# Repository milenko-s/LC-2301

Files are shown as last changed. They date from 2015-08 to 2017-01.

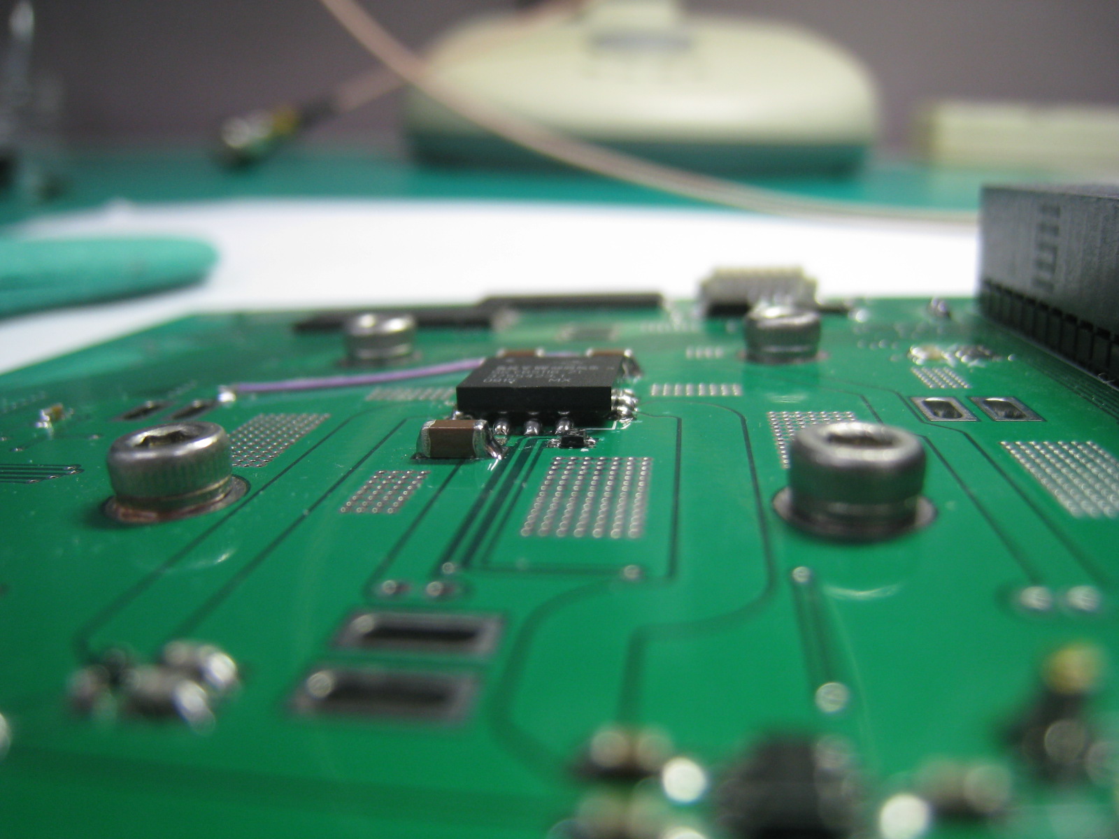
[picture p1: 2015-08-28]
documentation/pictures/IMG_1647.JPG

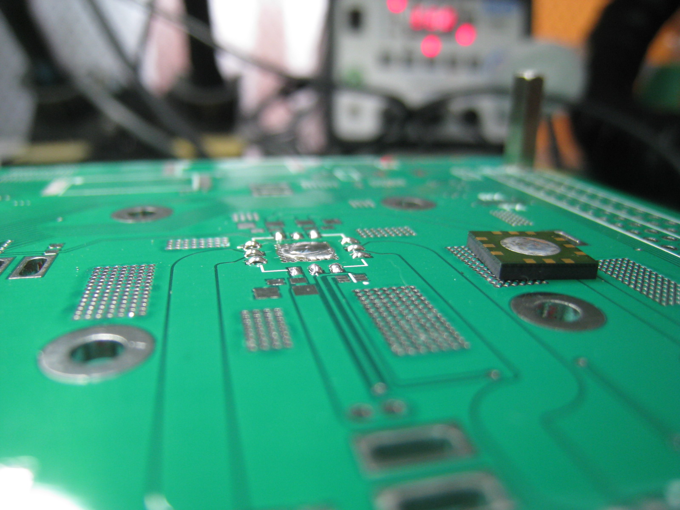
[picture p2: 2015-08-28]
documentation/pictures/IMG_1648.JPG

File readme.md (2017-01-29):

# LibreCube LC-2301 Communication System

## About

Half-duplex communication system for UHF band operation with radio output power of up to 31 dBm (>1 W). The output power, as well as the frequency and frequency separation are user-programmable, allowing large flexibility in operation. The device includes a beacon function that sends out a user-defined message in Morse code at adjustable keying speed, useful for satellite tracking and identification. The heart of the device is the establishment of a space link via ECSS/CCSDS compliant telecommand and telemetry frames (more correctly, CLTUs and CADUs, respectively). Beacon and telemetry frames are created and transmitted whenever such data is written to the device from an external device. Incoming telecommand frames are buffered in the device's memory, for successive read out from an external device. The physical layer of the space link uses FSK modulation at a data rate of 1200 bps (user-programmable). Further, a mechanism to support antenna deployment is included.

## Authors

- Artur Scholz [artur.scholz@librecube.net]
- Jesus Sanchez []
- Milenko Starcik []

## Acknowledgements

- Development supported from National Cheng Kung University (www.ncku.edu.tw) under supervision of Prof. Jiun-Jih Miau and Prof. Jyh-Ching Juang and with the help from students of PACELAB and MECLAB.

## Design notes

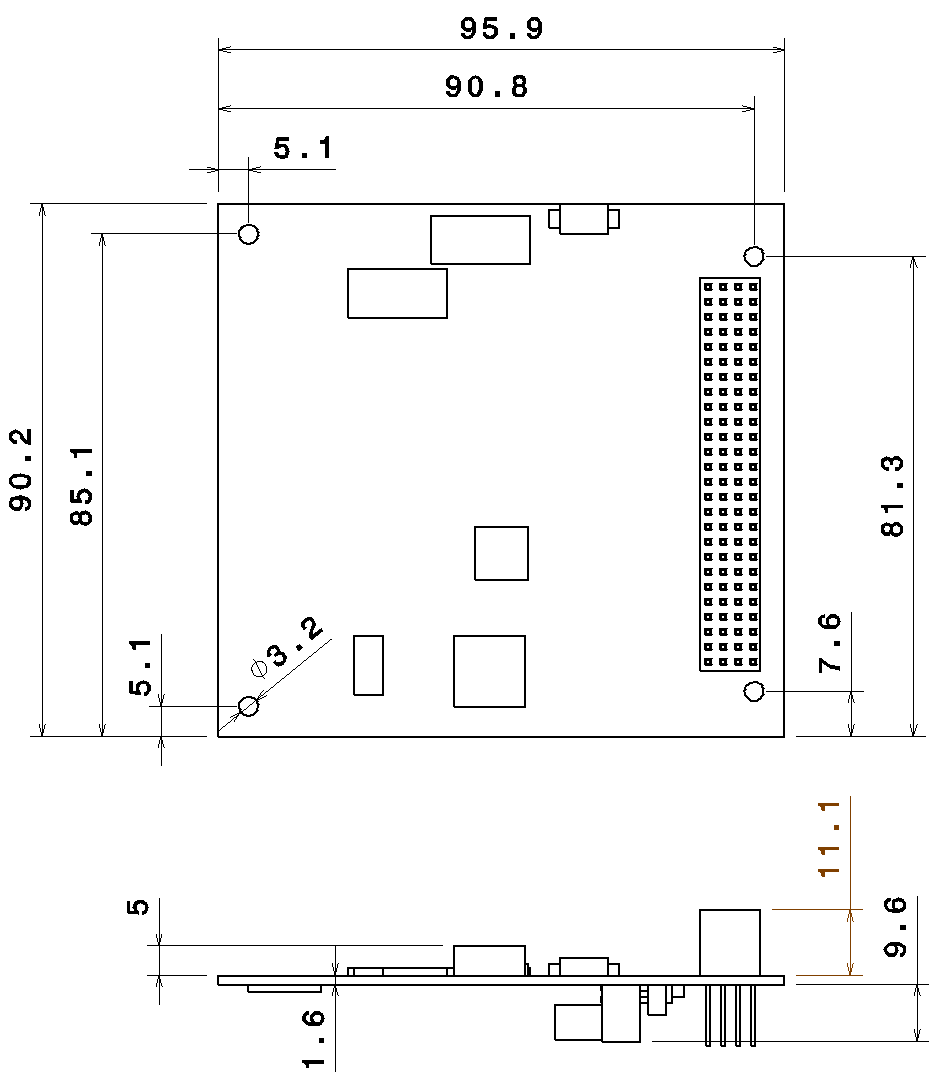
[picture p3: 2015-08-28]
documentation/figures/mechanical layout.tif

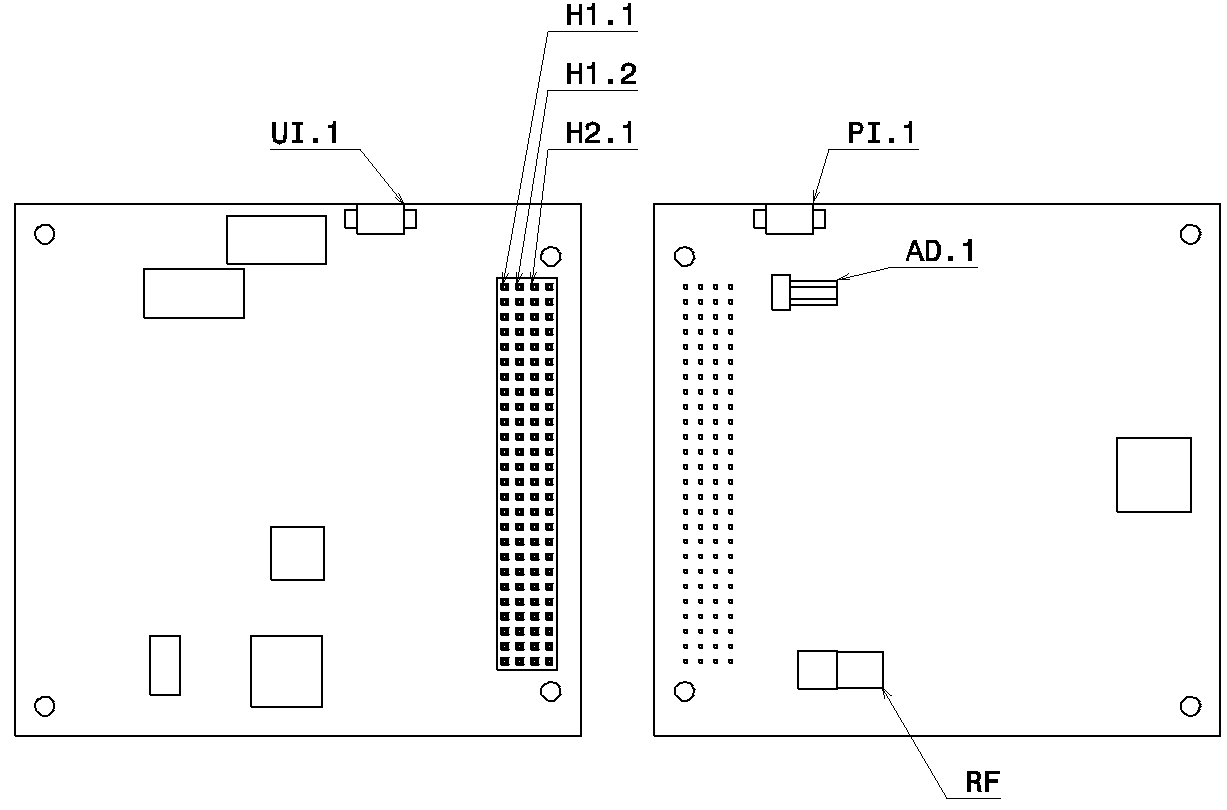
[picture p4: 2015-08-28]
documentation/figures/connector layout.tif

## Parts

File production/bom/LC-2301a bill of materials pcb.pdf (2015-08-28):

Sheet1

Page 1

LC-2301a Bill of Materials, PCB

Pos | Type | Description | Reference Designators | Qty | Vendor | Part Number | Unit Cost | Total Cost
1 | C | 0.1 uF | C1a, C1c, C1d, C4a, C5a | 5 | Digikey | 399-1097-1-ND | 0.10 € | 0.50 €
2 | C | 15 pF | C1e | 1 | Digikey | 445-1271-1-ND | 0.09 € | 0.09 €
3 | C | 0.01 uF | C1g, C3g, C5g, C7g | 4 | Digikey | 445-1311-1-ND | 0.09 € | 0.36 €
4 | C | 18 pF | C2a, C11e, C12e | 3 | Digikey | 445-1272-1-ND | 0.09 € | 0.27 €
5 | C | 0.47 uF | C2c | 1 | Digikey | 490-3295-1-ND | 0.18 € | 0.18 €
6 | C | 12 pF | C2e | 1 | Digikey | 445-1270-1-ND | 0.09 € | 0.09 €
7 | C | 10 uF | C2g, C4g, C6g, C8g | 4 | Digikey | 587-2562-1-ND | 0.56 € | 2.24 €
8 | C | 20 pF | C3a | 1 | Digikey | 478-7912-1-ND | 0.20 € | 0.20 €
9 | C | 220 pF | C3e | 1 | Digikey | 445-1285-1-ND | 0.09 € | 0.09 €
10 | C | 1 uF | C4e | 1 | Digikey | 490-5241-1-ND | 0.31 € | 0.31 €
11 | C | 8.2 pF | C5e | 1 | Digikey | 478-4997-1-ND | 0.21 € | 0.21 €
12 | C | 5.6 pF | C6e | 1 | Digikey | 399-9110-1-ND | 0.22 € | 0.22 €
13 | C | 3.3 uF | C7e | 1 | Digikey | 445-5168-1-ND | 0.25 € | 0.25 €
14 | C | 1 nF | C8e, C10e | 2 | Digikey | 490-1451-1-ND | 0.13 € | 0.26 €
15 | C | 33 nF | C9e | 1 | Digikey | 445-5093-1-ND | 0.09 € | 0.09 €
16 | C | 68 pF | C13e | 1 | Digikey | 445-1279-1-ND | 0.09 € | 0.09 €
17 | D | LED | D1a, D2a | 2 | Digikey | 160-1447-1-ND | 0.26 € | 0.52 €
18 | P | CubeSat ConnectoH1b | | 1 | Samtec | ESQ-126-39-G-D | 9.29 € | 9.29 €
19 | P | CubeSat ConnectoH2b | | 2 | Samtec | ESQ-126-39-G-S | 5.45 € | 10.90 €
20 | L | 12 nH | L1a | 1 | Digikey | PCD2003CT-ND | 0.12 € | 0.12 €
21 | L | BLM18HG102SN1L1e, L4e | | 2 | Digikey | 490-1034-1-ND | 0.17 € | 0.34 €
22 | L | 68 nH | L2e | 1 | Digikey | PCD2012CT-ND | 0.12 € | 0.12 €
23 | L | 6.2 nH | L3e | 1 | Digikey | 490-1163-1-ND | 0.29 € | 0.29 €
24 | L | 33 nH | L5e | 1 | Digikey | PCD2008CT-ND | 0.12 € | 0.12 €
25 | P | SMA | P1a | 1 | Digikey | ARFX1232-ND | 5.59 € | 5.59 €
26 | P | 2POS | P2a | 1 | Digikey | 732-2699-ND | 0.51 € | 0.51 €
27 | P | MICRO-06-R-SMTP3a | | 1 | Digikey | WM7624CT-ND | 1.44 € | 1.44 €
28 | R | 0.1 r | R1a | 1 | Digikey | CRA2512-FZ-R100ELFCT-ND | 0.63 € | 0.63 €
29 | R | 4.75 k | R1c | 1 | Digikey | P4.75KHCT-ND | 0.09 € | 0.09 €
30 | R | 10 k | R1e, R1f, R1g, R2a, R3g | 5 | Digikey | 311-10.0KHRCT-ND | 0.09 € | 0.45 €
31 | R | 100 k | R2c | 1 | Digikey | 311-100KGRCT-ND | 0.09 € | 0.09 €

Sheet1

Page 2

32 | R | 27 k | R2e | 1 | Digikey | RMCF0603JT27K0CT-ND | 0.09 € | 0.09 €
33 | R | 1.1 k | R2g | 1 | Digikey | P1.1KGCT-ND | 0.09 € | 0.09 €
34 | R | 1.5k | R3a, R4a | 2 | Digikey | P1.5KGCT-ND | 0.09 € | 0.18 €
35 | R | 82 k +/- 1% | R3e | 1 | Digikey | P82.0KHCT-ND | 0.09 € | 0.09 €
36 | R | 0 r | R5a, R6a | 2 | Digikey | P0.0GCT-ND | 0.09 € | 0.18 €
37 | IC | AS193-73 | U1a | 1 | Digikey | 863-1006-1-ND | 0.75 € | 0.75 €
38 | IC | C8051F120 | U1c | 1 | Digikey | 336-1223-ND | 15.65 € | 15.65 €
39 | IC | IS62WV5128BLL-5U1d | | 1 | Digikey | IS62WV5128BLL-55TLI-TR | 3.83 € | 3.83 €
40 | IC | CC1000 | U1e | 1 | Digikey | 296-19576-1-ND | 6.52 € | 6.52 €
41 | IC | TPS2024D | U1f, U2a | 2 | Digikey | 296-2564-1-ND | 2.23 € | 4.46 €
42 | IC | MAX893L | U1g | 1 | Digikey | MAX893LESA+-ND | 1.86 € | 1.86 €
43 | IC | REF3130 | U2c | 1 | Digikey | 296-17098-1-ND | 2.60 € | 2.60 €
44 | IC | RAMP-33LN+ | U2f | 1 | Digikey | *MINI-CIRCUITS: RAMP-33LN+ 18.77 € | | 18.77 €
45 | IC | SKY65116 | U2g | 1 | Digikey | 863-1072-1-ND | 5.34 € | 5.34 €
46 | IC | TMP20 | U3g | 1 | Digikey | 296-25570-1-ND | 0.98 € | 0.98 €
47 | X | 14.7456MHz_16pFX1e | | 1 | Digikey | 535-9633-1-ND | 0.81 € | 0.81 €
Total: | 98.15 €

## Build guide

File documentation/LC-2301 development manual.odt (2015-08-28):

Developer Manual

Communication System

Document change log

Rev. | Date | Author | Pages | Description
0 | 2014-06-27 | Artur Scholz | All | Created
1 | 2014-10-13 | Artur Scholz | 7 | Added information

# Introduction

This document provides the necessary information for production, assembly and firmware flashing of the product as shown in Illustration 1.

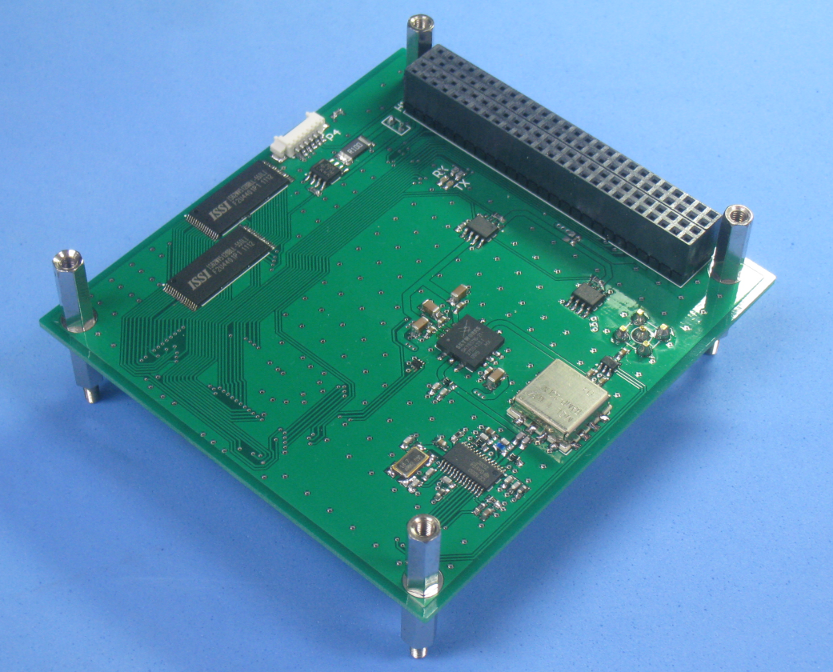
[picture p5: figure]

Illustration 1: Fully assembled product

# Applicable and reference documents

Reference | Title | Issue

# Definitions and abbreviations

Abbreviation | Definition

# Hardware

The product consists solely of a printed circuit board (PCB) assembly. The bill of materials (BOM) provides the list of items needed for the PCB assembly.

## PCB

With the provided Gerber files the double-sided PCB can be produced.

Good PCB layout is crucial to successful working and good performance. The reference layouts for the transceiver and power amplifier were closely followed. A high number of vias was used to interconnect all ground planes. The RF signal tracks to and from the power amplifier were given a width of 3.2 mm (rule of thumb: two times the height of the PCB) to yield 50 Ohm impedance.

The components are hand-soldered onto the PCB. The first part to mount is the high power amplifier (HPA). Attach small dots of solder tin on each pin of the IC and a larger and distributed amount on the center. Do the same for the pads on the PCB (Illustration 2). Key point is to have a solder film on each of the contacts. (It is absolutely important that the center pin has electrical contact!) Place the IC on the PCB and hold it in position with a Kapton tape (Illustration 3). Heat up the solder iron to around 450 °C, and hold it against the center pin vias from the other side of the PCB. Wait several seconds until it becomes apparent that the solder under the IC is liquid, and then remove the iron. In most cases it will be necessary to check the edge pins and solder them again after this procedure.

Illustration 2: Solder tin on pads

Illustration 3: Fixation of HPA chip

Using conductive glue instead of soldering for mounting the HPA is not recommended as it often results in poor conduction. After mounting, check the power amplifier module’s bias current (around 0.350 A without input signal) and output signal levels.

Next to mount is the TR switch, followed by transceiver and filter. Conduct test of the transceiver by checking its frequency range (smaller value for VCO inductor shifts to higher frequency) and check current consumption (in particular check that bias resistor is correct).

# Firmware

The firmware is the code that shall be programmed into the microcontroller on the PCB. The firmware has already been compiled and linked and is available as .OMF file for flashing (i.e. programming) of the microcontroller as explained in Section Flashing.

## Code editing and compiling/linking

A great and open source compiler for 8051 microcontrollers is SDCC (http://sdcc.sourceforge.net). This is the compiler used for generating the code contained in the repository. Alternatively one can use for example the free KEIL compiler.

As development environment, the author recommends the Eclipse platform with the SDCC plugin. This works great for Linux.

Alternatively, a Windows based IDE is the Silicon Laboratories IDE, which also provides for a debugger.

## Flashing

The flashing of the firmware code (as .OMF file) into the microcontroller is done using a USB JTAG Debug Adapter from Silicon Laboratories and the Silabs IDE. This only works with Windows unfortunately.

For the connection of the debug adapter to the device, a small interface board must be used in between, such as the LC-6101a. Alternatively, one can route the wires via a breadboard setup.

# Calibration

## Frequency and frequency separation calibration

The TX frequency settings should be programmed after the centre frequency and frequency deviation is defined. The 3-byte value to be written in the transceiver register is obtained for a desired frequency according to:

For the TX frequency, replace X with the desired centre frequency minus frequency deviation. For the RX frequency, replace X with the desired centre frequency minus 150 kHz. Also note that although the formula is quite accurate it is necessary to tune the values by hand to obtain a perfect result for each individual device.

For the frequency separation (which is twice the frequency deviation from the centre frequency), the formula for determining the 2-byte register value is:

This yields a value of 13.333 for a 1 kHz separation.

## RSSI measurement

For calibration of the RSSI measurement, a signal generator shall be connected to the RF terminal. The input signal is set to the frequency and frequency separation as programmed for the transceiver, and its output power is varied, while noting down the RSSI measurements. Obtain gain and offset from a linear least square fitting line.

## Temperature measurements

For calibration of the temperature measurements, the device shall be put in a thermally controlled environment, with temperature sensors placed on the temperature measurement locations. The measured temperatures together with the reference measurements shall be noted down for various temperatures. Obtain gain and offset from a linear least square fitting line.

Communication System Ref : LC-2301-MAN-01 Issue : 1 Rev. : 1 Date : 2014-10-13 LC-2301 Page : 6

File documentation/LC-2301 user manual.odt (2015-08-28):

User Manual

Communication System

Document change log

Rev. | Date | Author | Pages | Description
0 | 2014-06-27 | Artur Scholz | All | Created
1 | 2014-12-23 | Artur Scholz | All | Major revision

# Introduction

The LC-2301a Communication System is a half-duplex communication system for UHF band operation with radio output power of up to 31 dBm (>1 W). The output power, the frequency and the frequency separation are user-programmable, allowing large flexibility in operation. The main function of the device is the receiving of telecommands and sending of telemetry over the space link and exposing this to the UART interface. The space link implements ECSS/CCSDS telecommand and telemetry frames (namely, CLTUs and CADUs). The physical layer of the space link uses binary FSK modulation at a default data rate of 1200 bps (user-programmable). Further, a mechanism to support antenna deployment is included.

Features:

- CubeSat and CubeSat Kit compatible with PC/104 form factor
- Industrial temperature range
- RF output power up to 31 dBm
- ECSS/CCSDS frame protocol for telecommands and telemetry
- Transceiver completely programmable
- Binary FSK at 1200 bps
- Operates in the UHF band (amateur radio band)
- Includes provisions for antenna deployment

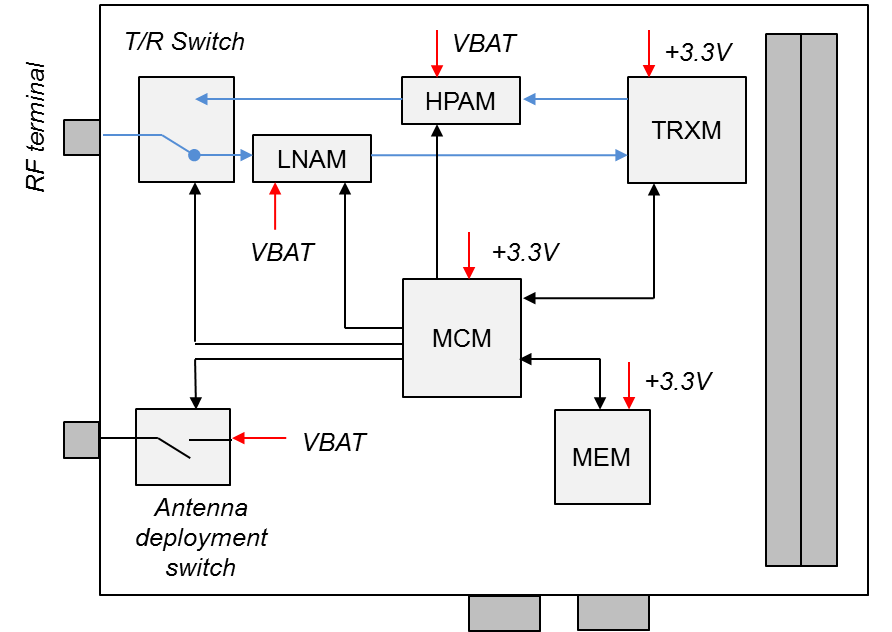
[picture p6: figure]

Illustration 1: System block diagram

# Applicable and reference documents

Reference | Title | Issue
AD01 | LibreCube Board Specification | 1

# Definitions and abbreviations

Abbreviation | Definition
ASM | Attached sync marker
CCSDS | Consultative Committee for Space Data Systems
CLTU | Communications link transmission unit
ECSS | European Cooperation on Space Standardization
HPAM | High power amplifier module
LNAM | Low noise amplifier module
MCM | Microcontroller module
MEM | Memory module
MSB | Most significant bit
RF | Radio frequency
RSSI | Received signal strength indication
TC | Telecommand
TM | Telemetry
TNC | Terminal node controller
TRXM | Transceiver module
WPM | Words per minute

# Specification

## Absolute maximum ratings

Parameter | Min | Max | Unit
Operational temperature range | -40 | 85 | °C
Supply voltage on +3.3V | | 3.6 | V
Supply voltage on VBAT | | 4.5 | V

| Exceeding the limits specified in the table above may result in permanent damage to the device and harm to products and personal.

## Physical characteristics

Parameter | Min | Nom | Max | Unit
Total mass | | 62.7 | | g
Height above PCB | | | 5 | mm
Height below PCB | | | 9.6 | mm
PCB width | | 95.9 | | mm
PCB length | | 90.2 | | mm
PCB thickness | | 1.6 | | mm

## Electrical characteristics

Parameter | Min | Nom | Max | Unit
Supply voltage on +3.3V | 3.0 | 3.3 | 3.6 | V
Supply voltage on VBAT* | 3.2 | 3.6 | 4.0 | V
Power consumption on +3.3V (idle) | | | 50 | mW
Power consumption on +3.3V (active) | 56 | | 66 | mW
Power consumption on VBAT (active) | 1.2 | | 4.2 | W
I2C node address (7 bit, hex) | | 0x13 | | -
I2C operating frequency | | 50 | 100 | kHz
Microcontroller operating frequency | | 6.125 | | MHz
Measurement resolution | | 12 | | bit
UART baud rate | | 9600 | | bps

*VBAT powers the LNAM and the HPAM

## RF and interface characteristics

Parameter | Min | Nom | Max | Unit
Antenna impedance (SMA connector) | | 50 | | Ohm
Centre frequency | 300 | 437 | 500 | MHz
Frequency programming steps | | 250 | | Hz
Frequency separation | 0 | 9.6 | 65 | kHz
Frequency sep. programming steps | | 250 | | Hz
RF baudrate | | 1200 | | bps
Transmit power | -17 | | 31 | dBm
Receiver sensitivity (BER = 10⁻³) | -95 | -105 | | dBm
Size of telecommand data buffer | | 65536 | | Byte
Size of telemetry data buffer | | 65536 | | Byte

# Interfaces

## Mechanical interfaces

The mechanical layout of the device is shown in Illustration 2. Four ø3.2 mm holes are located on the corners for mounting with M3 screws. The CubeSat connector is available in stack-through (as shown) and non-stack-through option.


Illustration 2: Mechanical layout

## Electrical interfaces

All available connectors on the top and bottom of the board are shown in Illustration 3. Note that the arrow points to the location of pin 1 for each connector. The signals of each connector are described in Table 1 to Table 4.


Illustration 3: Connector layout

Table 1: Antenna deployment connector

Pin | Description
AD.1 | Connects to battery supply during deployment. Otherwise open.
AD.2 | Ground

Table 2: RF interface connector

Pin | Description
- | RF signal
- | Ground (shielding)

Table 3: Programming interface connector

Pin | Signal | Description
PI.1 | +3.3V | +3.3V power supply
PI.2 | TMS | JTAG TMS signal
PI.3 | TCK | JTAG TCK signal
PI.4 | TDI | JTAG TDI signal
PI.5 | TDO | JTAG TDO signal
PI.6 | GND | Ground.

| The programming interface is used for updating the firmware.

Table 4: CubeSat connector

Pin | Signal | Description
H1.29 | -RESET | System reset line. Active low. Causes MCU to reboot.
H1.39 | TX0 | TX of UART0 for data to be transmitted via communication system.
H1.40 | RX0 | RX of UART0 for data received via communication system.
H1.41 | SDA0 | I2C system bus data
H1.43 | SCL0 | I2C system bus clock
H2.27, 28 | +3.3V | +3.3V power supply
H2.29, 30, 32 | DGND | Ground
H2.45, 46 | VBAT | Battery power supply (3.2 V – 4.0 V)

| H1 | | | | | H2
| 1 | 2 | | | | 1 | 2
| 3 | 4 | | | | 3 | 4
| 5 | 6 | | | | 5 | 6
| 7 | 8 | | | | 7 | 8
| 9 | 10 | | | | 9 | 10
| 11 | 12 | | | | 11 | 12
| 13 | 14 | | | | 13 | 14
| 15 | 16 | | | | 15 | 16
| 17 | 18 | | | | 17 | 18
| 19 | 20 | | | | 19 | 20
| 21 | 22 | | | | 21 | 22
| 23 | 24 | | | | 23 | 24
| 25 | 26 | | | | 25 | 26
| 27 | 28 | | | +3.3V | 27 | 28 | +3.3V
-RESET | 29 | 30 | | | DGND | 29 | 30 | DGND
| 31 | 32 | | | AGND | 31 | 32 | DGND
| 33 | 34 | | | | 33 | 34
| 35 | 36 | | | | 35 | 36
| 37 | 38 | | | | 37 | 38
TX0 | 39 | 40 | RX0 | | | 39 | 40
SDA0 | 41 | 42 | | | | 41 | 42
SCL0 | 43 | 44 | | | | 43 | 44
| 45 | 46 | | | VBAT | 45 | 46 | VBAT
| 47 | 48 | | | | 47 | 48
| 49 | 50 | | | | 49 | 50
| 51 | 52 | | | | 51 | 52

Illustration 4: CubeSat connector pin layout

## Software interfaces

Interfacing for monitoring and control is accomplished via I2C bus. The device always operates as slave. A master can read and write the values of the internal registers of the device. The following paragraphs describe how to read and write the registers.

### Write operation

The master initiates a write operation by issuing a START condition followed by the device’s slave address and a WRITE bit (0). When the master receives an ACKNOWLEDGE from the device it can transmit the 8-bit register address. The device will respond with a second ACKNOWLEDGE. The master then transmits the 8-bit value that shall be loaded into this register. The slave will respond with a third ACKNOWLEDGE. The write operation is then completed when the master issues a STOP condition or a second START condition.

S | Device Address | W | A | Register Address | A | Value | A | P

### Read operation

The master initializes a read operation with a START condition followed by the device’s slave address and a WRITE bit (0). When the master receives an ACKNOWLEDGE from the device it can transmit the 8-bit register address. The device will respond with a second ACKNOWLEDGE. The master must then issue a new START condition followed by the device’s slave address and a READ bit (1). The sensor will respond with an ACKNOWLEDGE followed by the value of the register. The master must issue a NOT ACKNOWLEDGE followed by a STOP condition to terminate the operation.

S | Device Address | W | A | Register Address | A | S | Device address | R | A | Value | NA | P

### Bit operations

The read and write operations operate on the basis of single bytes. In order to set or clear single bits from the internal register without changing the other bits of that register, the register must be first read out, then be subjected to AND/OR operation for clearing/setting a single or multiple bits, and finally the result must be written back to the register.

### Device register

Writing and reading of the device registers allows full control and knowledge about the device. The content of the register is shown in Table 5. It is divided into segments that group related registers together.

Table 5: Device register

Add (hex) | Register name | Default | Read / Write | Note | Segment
0x00 | null | - | - | | Main
0x01 | cmd | - | W | Command input
0x02 | hkperiod | 1 Hz | R/W | Sets HK period | Settings
0x03 | measure | All | R/W | Sets measurement mode
0x04 | tm_power | 26 dBm | R | FM transmit power
0x05 | frx_l | 436.850 MHz | R | Receive frequency
0x06 | frx_m | | R
0x07 | frx_h | | R
0x08 | ftx_l | 436.995 MHz | R | Transmit frequency minus half of frequency separation
0x09 | ftx_m | | R
0x0A | ftx_h | | R
0x0B | fsep_l | 9.6 kHz | R | Frequency separation
0x0C | fsep_h | | R
0x0D | flag | - | R | System flags | Flags
0x0E | mcutemp_l | - | R | MCU temperature | Values
0x0F | mcutemp_h | - | R
0x10 | hpatemp_l | - | R | HPA temperature
0x11 | hpatemp_h | - | R
0x12 | rssi_l | - | R | RSSI level
0x13 | rssi_h | - | R
0x14 | tc_byte_counter_l | - | R | Counter of received TC bytes
0x15 | tc_byte_counter_m | - | R
0x16 | tc_byte_counter_h
0x17 | tm_byte_counter_l | | | Counter of transmitted TM bytes
0x18 | tm_byte_counter_m
0x19 | tm_byte_counter_h

Table 6 provides detailed information about all of the not self-explanatory registers listed in Table 5. Each register is 8 bit, and as structured as shown below.

<register name>
Bit 7 MSB | Bit 6 | Bit 5 | Bit 4 | Bit 3 | Bit 2 | Bit 1 | Bit 0 LSB

Table 6: Detailed description of registers

Register | Description
cmd | Command input register. The following commands are defined: Opcode Mnemonic Description 0x01 RESET Triggers a microcontroller reset. 0x02 MEASURE Triggers a manual refreshment of measurements. 0x03 UPDATE_TRX Updates the transceiver to the settings given in registers 0x08 to 0x0F. 0x04 DEPLOY_ANT Powers the antenna deployment circuit for a fixed duration of one second. 0x05 TX_ENABLE Enable the transmission of data over the space link. 0x06 TX_DISABLE Disabled the transmission of data over space link.
hkperiod | Sets the refreshment cycle of measurements for the housekeeping data, in steps of 1/10 seconds. Set to zero to disable automatic refreshment.
measure | Defines which of the measurement types are updated when a measurement is triggered (manual or via automatic refreshment). Set or clear the following bits: Bit 0: temperature Bit 1: rssi
tm_power | Adjusts the RF output power of telemetry frames. Settings are not linear and must be calibrated. Changes have immideate effect.
frx_[l/m/h] | Receiver frequency setting.
ftx_[l/m/h] | Transceiver frequency setting.
fsep_[l/h] | Frequency separation setting.

flag

This register holds the flags of system events.

Bit | Name | Description
0 | busy | Flag is set when device is not idle, that is when doing measurements for the housekeeping, or transmitting/receiving data over the space link.
1 | complete | Flag is set when the recent measurements for the housekeeping have completed.
2 | sending_tm_data | This bit is set during the transmission of TM frame over the space link.
3 | receiving_tc_data | This bit is set whenever the device has found the CLTU start sequence in the received space link, and is busy with processing the incoming frame.
4 | antenna_deploying | This flag is set when the antenna deployment is ongoing.
5 | rf_bitlock | Same as bit 3.
6 | tx_enabled | This bit is set when TX is enabled.
7 | tx_on | This bit is set when TX is on. Same as bit 2.
mcutemp_l/h | Contains low byte and high byte of temperature measurement code (at microcontroller). Convert to Celsius according to¹: Temperature [Celsius] = gain * code + offset
hpatemp_l/h | Contains low byte and high byte of temperature measurement code (at HPA). Convert to Celsius according to¹: Temperature [Celsius] = gain * code + offset
rssi_l/h | Contains low byte and high byte of RSSI measurement code. Convert to Celsius according to¹: P[dBm] = gain * code + offset

¹ The values for gain and offset are determined during calibration.

# Design description

## Hardware

### Transceiver module (TRXM)

The transceiver is a single-chip UHF transceiver IC (CC1000 from Texas Instruments). A block diagram of the chip is given in Illustration 5.

Illustration 5: Block diagram of CC1000 transceiver

The receiver part is built as a traditional super-heterodyne down-conversion receiver (Illustration 6). The incoming RF signal is amplified in the LNA and then fed into the mixer. The mixer takes the input frequency fIN from the LNA and the frequency fLO from the local oscillator (which is a voltage controlled oscillator tuned to a specific frequency as described later) and produces the sum and difference frequencies (and harmonics), fIN + fLO and fIN – fLO respectively. The CC1000 uses an intermediate frequency (IF) of 150 kHz, and to achieve low-side injection (where the digital output data will not be inverted as for high-side injection) the LO is tuned to fIN – fIF. The result is that the original FSK signal with centre frequency of fRF is converted to a fixed centre frequency fIF, while retaining the frequency deviation (e.g. ±5 kHz) between ‘0’ and ‘1’. The output of the mixer is band-pass filtered to remove fIN + fLO and reduce harmonics. This signal is filtered and amplified and then fed to the demodulator. The data and clock are provided at DIO and DCLK respectively. The data at DIO is valid at the rising edge of DCLK.

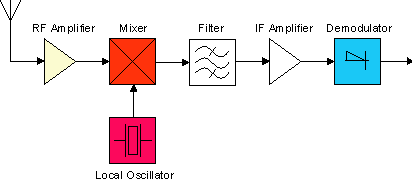
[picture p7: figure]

Illustration 6: Concept of super-heterodyne receiver

During transmit mode the timing clock is provided at DCLK (whose frequency is defined by the baud rate setting). The data at DIO is latched at the rising edge of DCLK. The VCO signal is directly fed to the internal power amplifier (PA). The RF output is frequency shift keyed (FSK). The VCO is the f0 frequency for a ‘0’ and f0 + fSEP is a ‘1’. The frequency separation fSEP can be programmed in steps of 250 Hz. Illustration 7 pictures the relevant frequencies for receive and transmit mode.

Illustration 7: Frequency settings for TX and RX

The key blocks in the transceiver are described in the following in more detail.

The demodulator block samples the frequency and converts it to a voltage level. This level is (after quantization and filtering) compared to the value of the average filter to generate the data output. The average filter is used to find the average value of the incoming data.

The VCO uses an external inductor, which determines the operating range of the circuit. The tuning range limits can be tested as described in AN018 page 2. The frequency of operation should be ideally located somewhere near the center of this range.

The wide tuning range of a VCO is combined with an inherently high frequency stable crystal oscillator (XOSC) to do frequency synthesis in form of a phase-locked loop (PLL).

The phase detector compares the (R-divided) XOSC reference input with the feedback of the (N-divided) VCO and produces an error signal which is proportional to their phase difference. The error signal is then low-pass filtered (to remove AC variations and noise) and used to drive a VCO which creates an output phase. If the output phase drifts, the error signal will increase, driving the VCO phase in the opposite direction so as to reduce the error. Thus the output phase is locked to the phase at the reference input.

The matching of the RF input and output pins for the CC1000 is accomplished as described in the data sheet.

### High power amplifier module (HPAM)

The fully matched (50 Ohm) high power amplifier IC provides high gain of 35 dB and an output power of P1dB = 32.5 dBm. The power is taken directly from the battery supply to support the high current of ICC = 1.3 A at maximum RF output. The PA gets very hot during operation and needs appropriate cooling in form of a large ground plane The PA block diagram is shown in Illustration 8. A current limiting IC is included in the supply line of the HPA to limit maximum current to about 1.3 Ampere, for safety reasons. The HPA is only powered when TX is enabled.

Illustration 8: Block diagram of HPA

### Low noise amplifier module (LNAM)

A low noise amplifier IC is used to improve the signal quality of the received signal before going into the transceiver. The LNA is constantly powered.

### Filter

The output of transceiver contains harmonics (integer multiples of the operating frequency), that should be filtered out before the power amplifier stage. A simple Pi-type low-pass filter as shown in Illustration 9 is utilized.

A band-pass filter to reject out-of-band signals at the receiver front-end is usually not necessary for space applications, as the problem of IDM (intermodulation distortion) or image noise is not dominant (because this would require other ground stations to actively transmit signals to the receiver system).

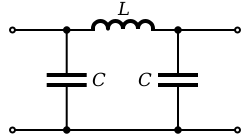
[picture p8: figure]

Illustration 9: Pi-type low-pass filter

### Duplexer

The duplexer is used for switching the antenna between the TX output and RX input of the transceiver, as the device only operates on a single frequency, and must therefore use half-duplex communication.

### Antenna deployment module (ADM)

The antenna deployment module is simply a power switch that connects the VBATT voltage to the antenna deployment mechanisms (an external coil). A low-value resistor is inserted in the path to allow current limiting.

### Memory module (MEM)

The memory module is a volatile SRAM, which us used as a buffer. It buffers a single beacon/frame coming in via the UART data bus before it is transmitted over the space link. It also buffers the received CLTUs coming from the space link.

### Microcontroller module (MCM)

The microcontroller is a 8051 device. The MCU runs at 6.1256 MHz, which is enough for the baud rate of 1200 bps (high baud rate may require the MCU to run at higher speeds).

## Software description

### Functional overview

The functionality of the device is to:

- constantly search the incoming bit stream from the receiver for telecommands (in form of CLTUs), and buffer them
- route completely received telecommands to UART
- receive telemetry data from UART and send over the space link
- provide antenna deployment support
- produce housekeeping data

## Software implementation

### Main loop

Following initialization, the main loop checks for received commands (from a I2C master device) and periodically refreshes its housekeeping information (unless disabled). Then it looks if there are telecommand data bytes in the FIFO, and routes them to the UART, one byte per loop iteration. The last step of the loop is to check if there is telecommand data in the FIFO. If so, it will send it over the space link, one byte per loop iteration. It also takes care of activating TX at start of transfer and deactivation when the FIFO is emptied.

### Telecommand reception

A timer (Timer 0) interrupt is triggered every 50 microseconds, which checks if a new bit has arrived. If so, this bit is shifted into a 16 bit buffer. This buffer is then compared to the CLTU start sequence (0xEB90). If it matches, a function for buffering the incoming CLTU is called. The structure of a CLTU is as shown:

CLTU – Command Link Transmission Unit
Start Sequence 0xEB90 | 1st Codeblock | 2nd Codeblock | ... | n-th Codeblock | Tail sequence
2 byte | 8 byte | 8 byte | | 8 byte | 8 byte

Valid tail sequence: 0xC5 0xC5 0xC5 0xC5 0xC5 0xC5 0xC5 0x79

or: 0x55 0x55 0x55 0x55 0x55 0x55 0x55 0x55

The device does not check any of the payload data for errors, it solely looks for the start sequence, incoming data, and finally the tail sequence, and pushes all of it in the telecommand FIFO buffer.

Note that CLTUs can have variable length, therefore the tail sequence is needed for detecting the end of each CLTU. However, there is a maximum allowed CLTU length defined in software, for the purpose of preventing a corrupted or lost tail sequence to cause a buffer overflow.

### Telemetry transmission

For sending telemetry over the space link, an attached device simply needs to write the data to the UART connection. The data is received via the UART interrupt service routine byte for byte and added to the telemetry FIFO buffer.

Basically the telemetry data frame can have any structure and format, and hence any downlink protocol can be implemented by the master. Nonetheless, the device is supposed to use CCSDS telemetry frames, and therefore the data should be structured (as provided by the master device) as follows:

CADU – Channel Access Data Unit
Attached Synch Marker 0x1ACFFC1D | Data
4 byte | Fixed, max. 2048 byte

Note that telemetry frames (and hence CADUs), have a defined fixed length throughout the mission. This is needed in order to help the ground segment to synchronize.

# Handling and storage

When handling the device make sure that it is powered off. To do so, disconnect all power lines from the device. For transportation put the device into an ESD protective bag and a box. For storage of the device ensure that it is in powered off. Store the device in an ESD protective bag in a dry, clean environment preferably at room temperature.

| Be careful when making modifications to the board electronics. Avoid touching the board circuitry when handling. Mistreatment may result in damage.

# Experimental usage

## Set up for testing

1. When setting up the device for in-lab operation, place it on a horizontal surface that is preferably covered by an ESD mat. Make sure that the device is powered off.
2. Attach antenna to the device via a coax cable.
3. Attach power supply cables to the 3.3V land VBAT pin. Alternatively, stack a power supply board (such as LC-2201a or similar) onto it. Make sure that at this step the device is not yet powered.
4. To connect the device to a computer for monitoring and control use an I2C-UART bridge (LC-3101a or similar). Use the CubeSat board connector for connecting the SDA0, SCL0, +3.3V, and GND pins.
5. To connect the device to a computer for transfer of data use a UART adapter (LC-3102a or similar). Connect the TX0, RX0, +3.3V, and GND pins from the device's CubeSat connector to the adapter. See Illustration 10.
6. Power the device by switching on the external power supply.

Illustration 10: In-lab set-up (power supply not shown)

## Test procedures

### Reading from the device via I2C bus

For example, to read the housekeeping setting of the device, send the following two bytes via the terminal program: 0x27 0x02. The first byte is the device 7 bit I2C address appended by 1 bit for the read operation. The second byte is the register address from which to read. The device will respond with the default value of 0x0A.

### Writing to the device via I2C bus

As another example, to set the housekeeping refresh rate to every 2 seconds, send the following: 0x26 0x02 0x14. The first is the 7 bit I2C address shifted to left one bit, followed by the register address, and the value to be written (20 decimal).

### Sending telemetry

To send telemetry, simply write data to the TX0 port of the CubeSat board connector.

### Receiving telecommands

When valid telecommands (i.e. CLTUs) are received, they are automatically routed to the RX0 port at the CubeSat board connector.

# Operational usage

## System integration

### Mating with other boards

To integrate the device into a satellite it can be stacked onto other electronic boards that comply with the CubeSat connector layout. Use M3x15 mm spacers between the boards. (If such a stacked configuration is not feasible or desired, another option would be to route the electrical signals from the CubeSat connector via harness to the other subsystems.)

| Make sure that all devices are powered off during mating.

| Before mating the device with other boards make sure that the electrical connections are compatible with each other and remain within their specified levels at all times.

### Antenna attachment

Connect a 50 ohm antenna for UHF band to the SMA terminal of the device via a 50 ohm coaxial cable. If the antenna or cable is not properly matched to 50 ohm, attenuation will be introduced. In case of excessive mismatch this may result in damage to the transmitter.

| Always make sure that a 50 Ohm antenna (or dummy load) is properly connected to the device before operation.

### Antenna deployment mechanism attachment

An antenna deployment circuitry is implemented on the device that essentially consists of an active low switch, controlled via the device’s register. When the switch is activated, the antenna deployment positive terminal will be connected to VBAT, which may be used to active an external antenna deployment mechanisms (such as melting a wire or releasing a hook).

## Operations procedures

### Control and monitoring

For control and monitoring of the device, the device’s registers are used as described in section 5.3. To achieve this, an external controller (on board computer) must operate on the I2C bus to read and write the registers of the device.

### Housekeeping

The device periodically captures housekeeping data and updates the corresponding registers at periods defined in the hkperiod register. This function can be disabled. A manual triggering of housekeeping capture can be triggered via command. The housekeeping data consists of analog measurements and status bits as described in the next section. The measure register defines which measurements to update.

### Measurements

The device provides two types of measurements. Temperature measurements from MCU and HPA are available. The locations are shown in Illustration 11. The RSSI measurement provides an indication on the strength of a received signal.

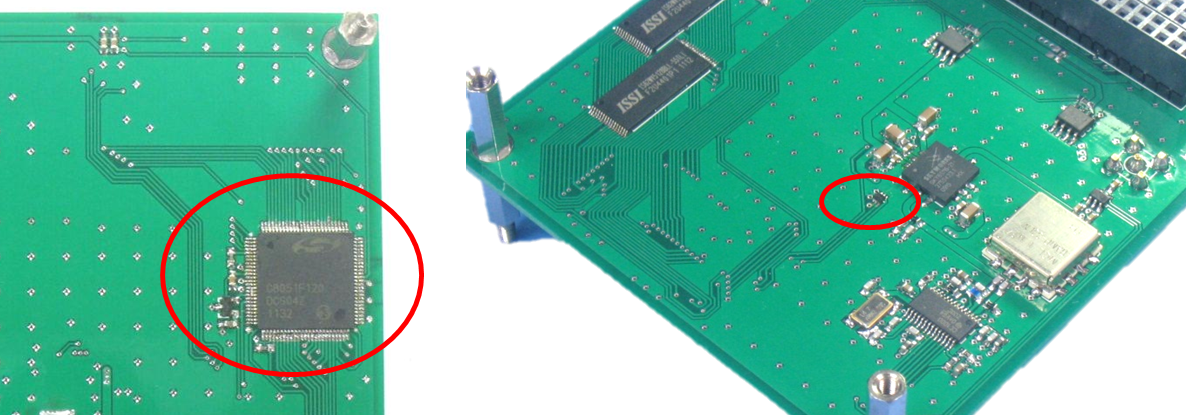
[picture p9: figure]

Illustration 11: Location of temperature measurements

### Sending telemetry

Same as Section 8.2.3.

### Receiving telecommands

Same as Section 8.2.4.

### Antenna deployment

Send the relevant command to the device via the I2C bus.

Communication System Ref : LC-2301-MAN-01 Issue : 1 Rev. : 1 Date : 2014-12-23 LC-2301 Page : 1

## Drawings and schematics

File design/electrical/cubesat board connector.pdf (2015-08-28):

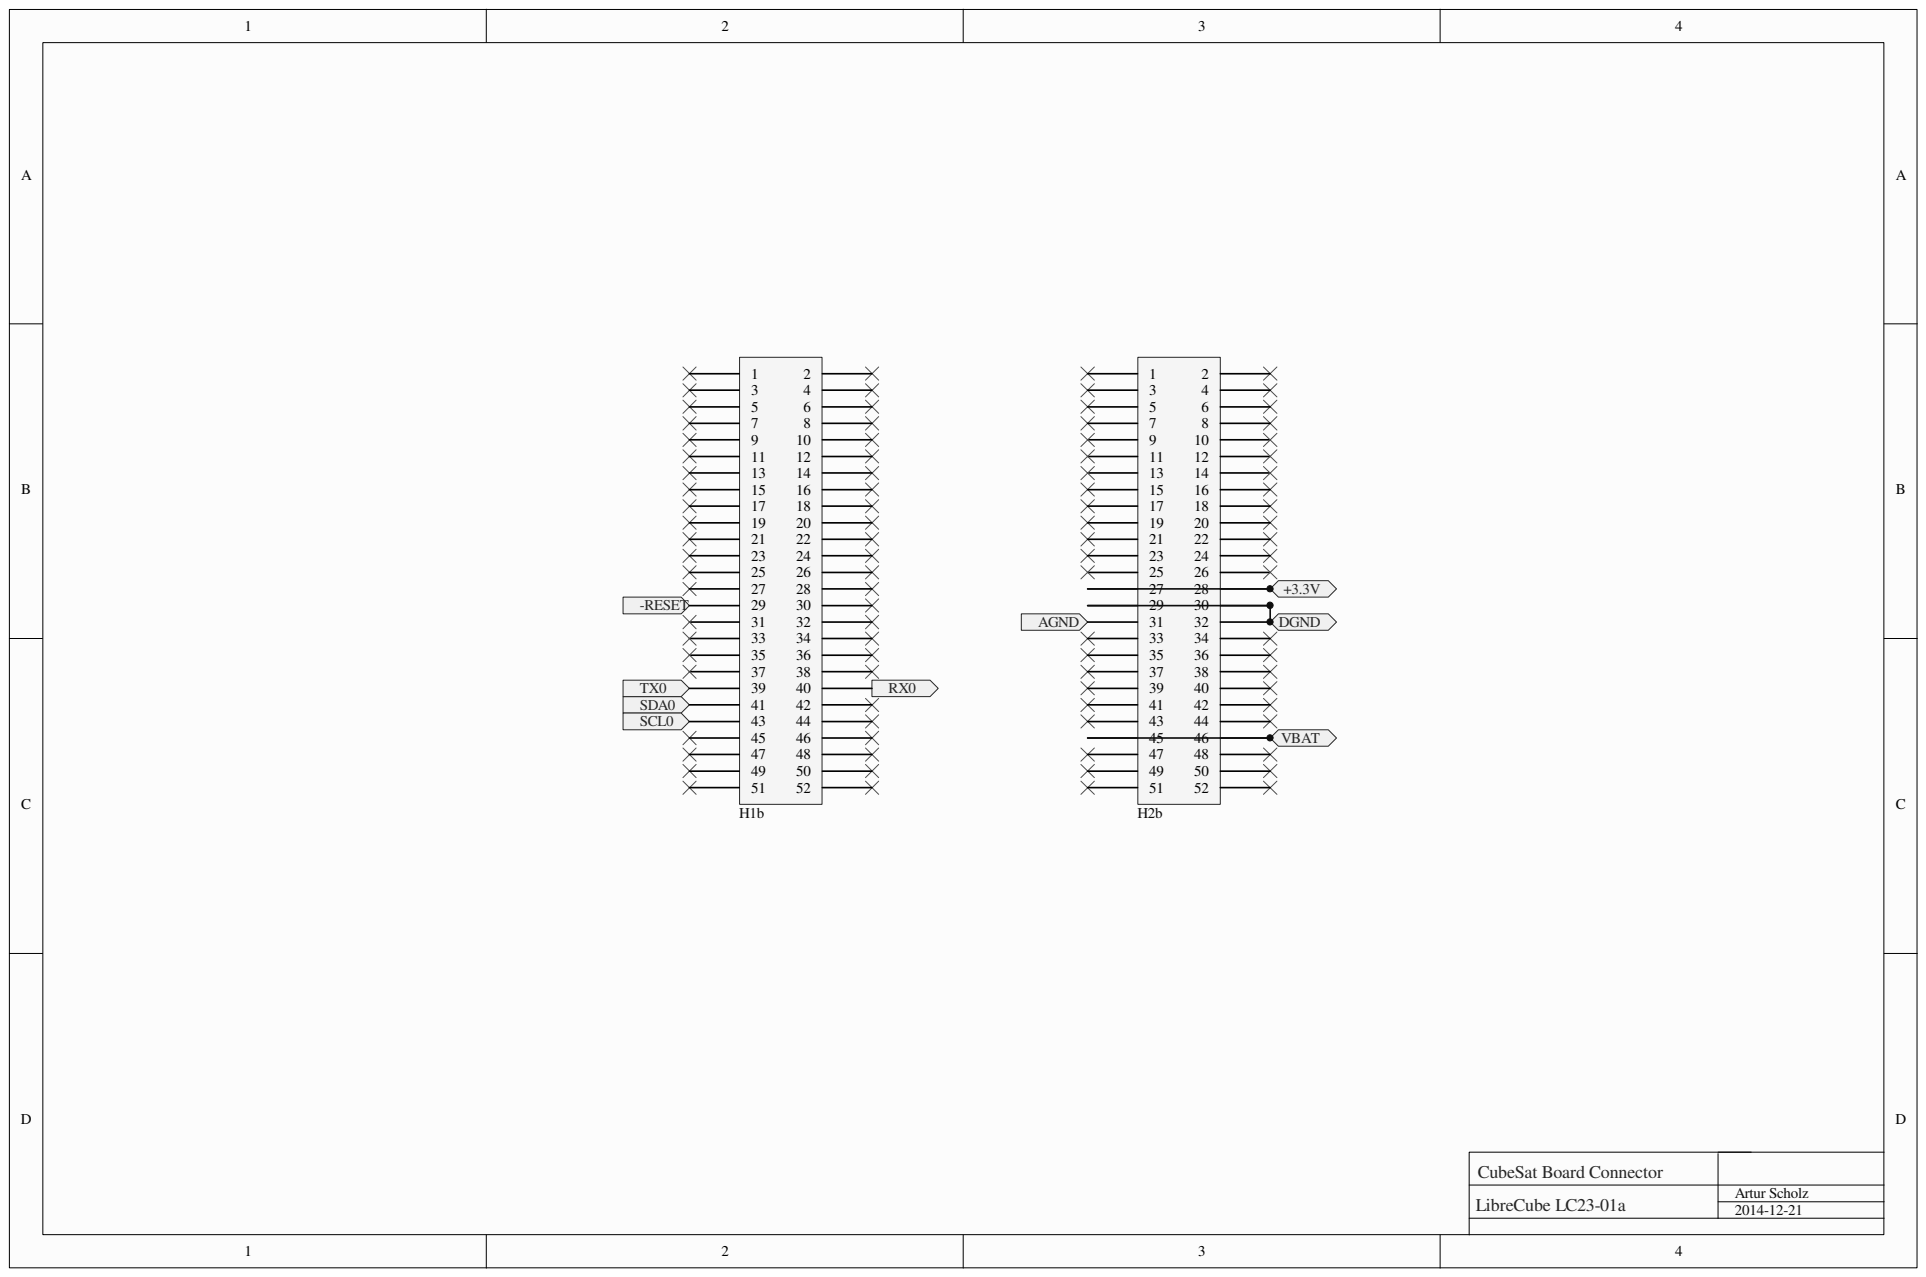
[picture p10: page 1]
Artur Scholz; LibreCube LC23-01a; SDA0 SCL0; -RESET; VBAT; AGND; DGND

CubeSat Board Connector

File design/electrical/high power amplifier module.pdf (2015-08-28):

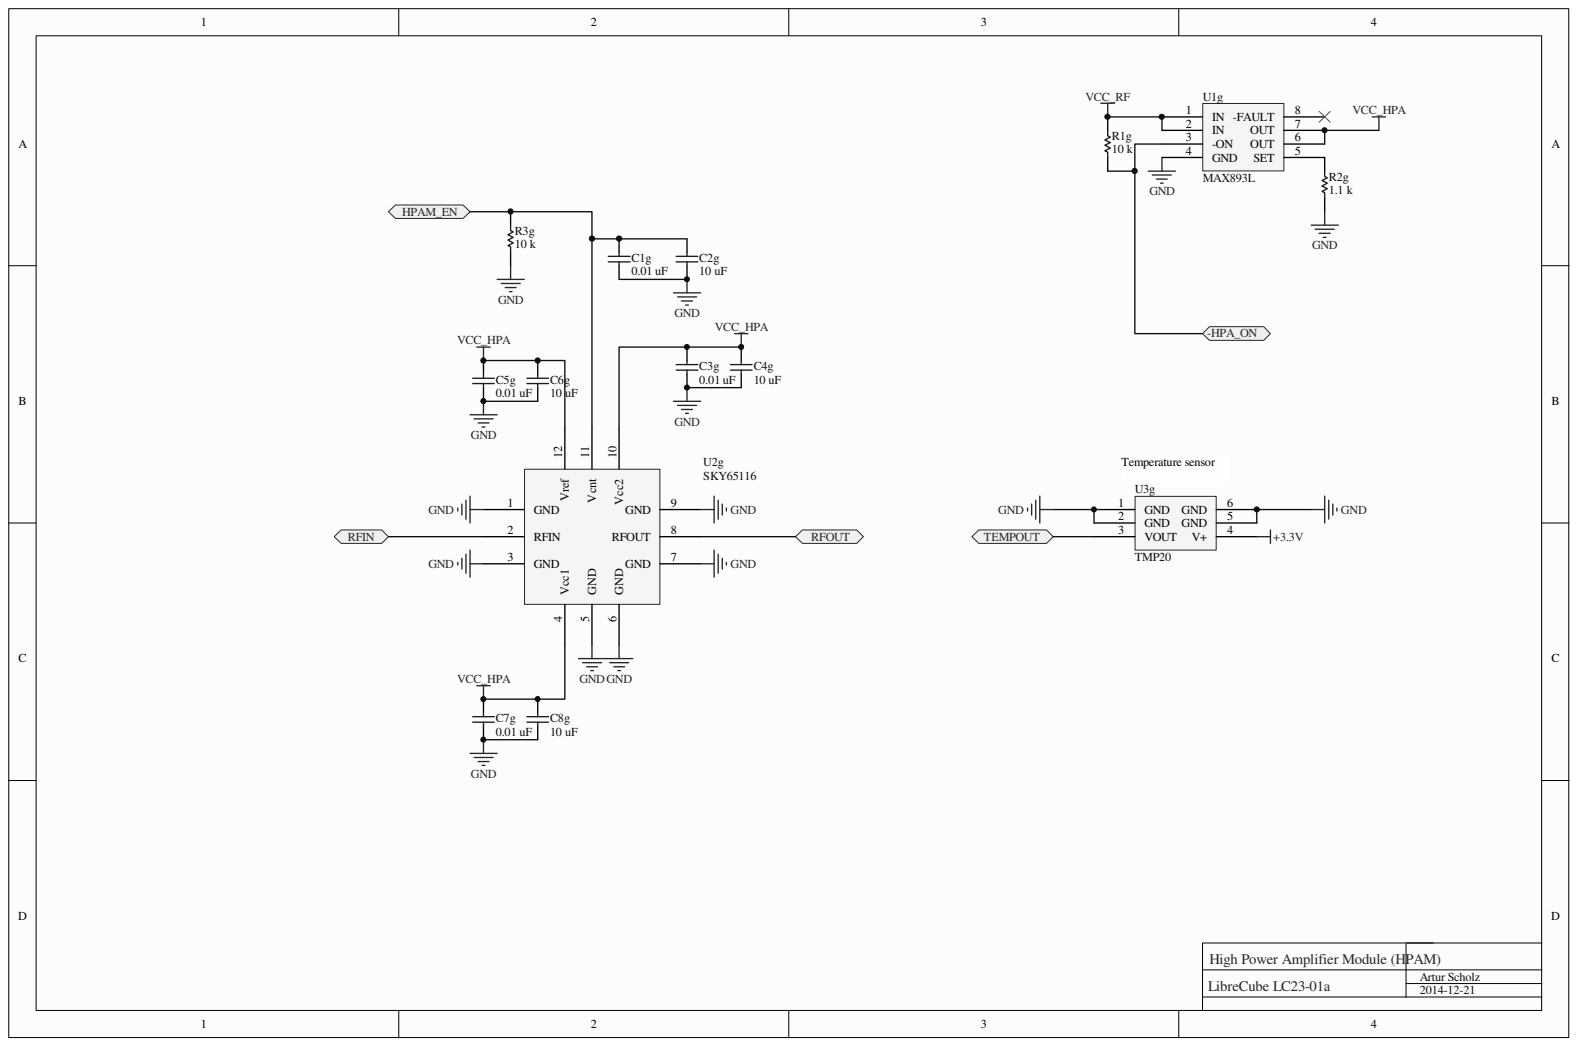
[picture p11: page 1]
Artur Scholz; LibreCube LC23-01a; GND 1; RFIN 2; GND 3; Vcc1; GND; RFOUT; Vcc2 9; Vcnt; Vref; U2g SKY65116; GNDGND; RFIN; VCC_HPA; HPAM_EN; GND 1 GND 2; VOUT 3; 4 GND; 5 GND; TMP20; Temperature sensor; TEMPOUT; VCC_RF; VCC_HPA IN 1 IN 2 -ON 3; GND 4; SET; 5 OUT; 6 OUT; 7 -FAULT; MAX893L; -HPA_ON

High Power Amplifier Module (HPAM)

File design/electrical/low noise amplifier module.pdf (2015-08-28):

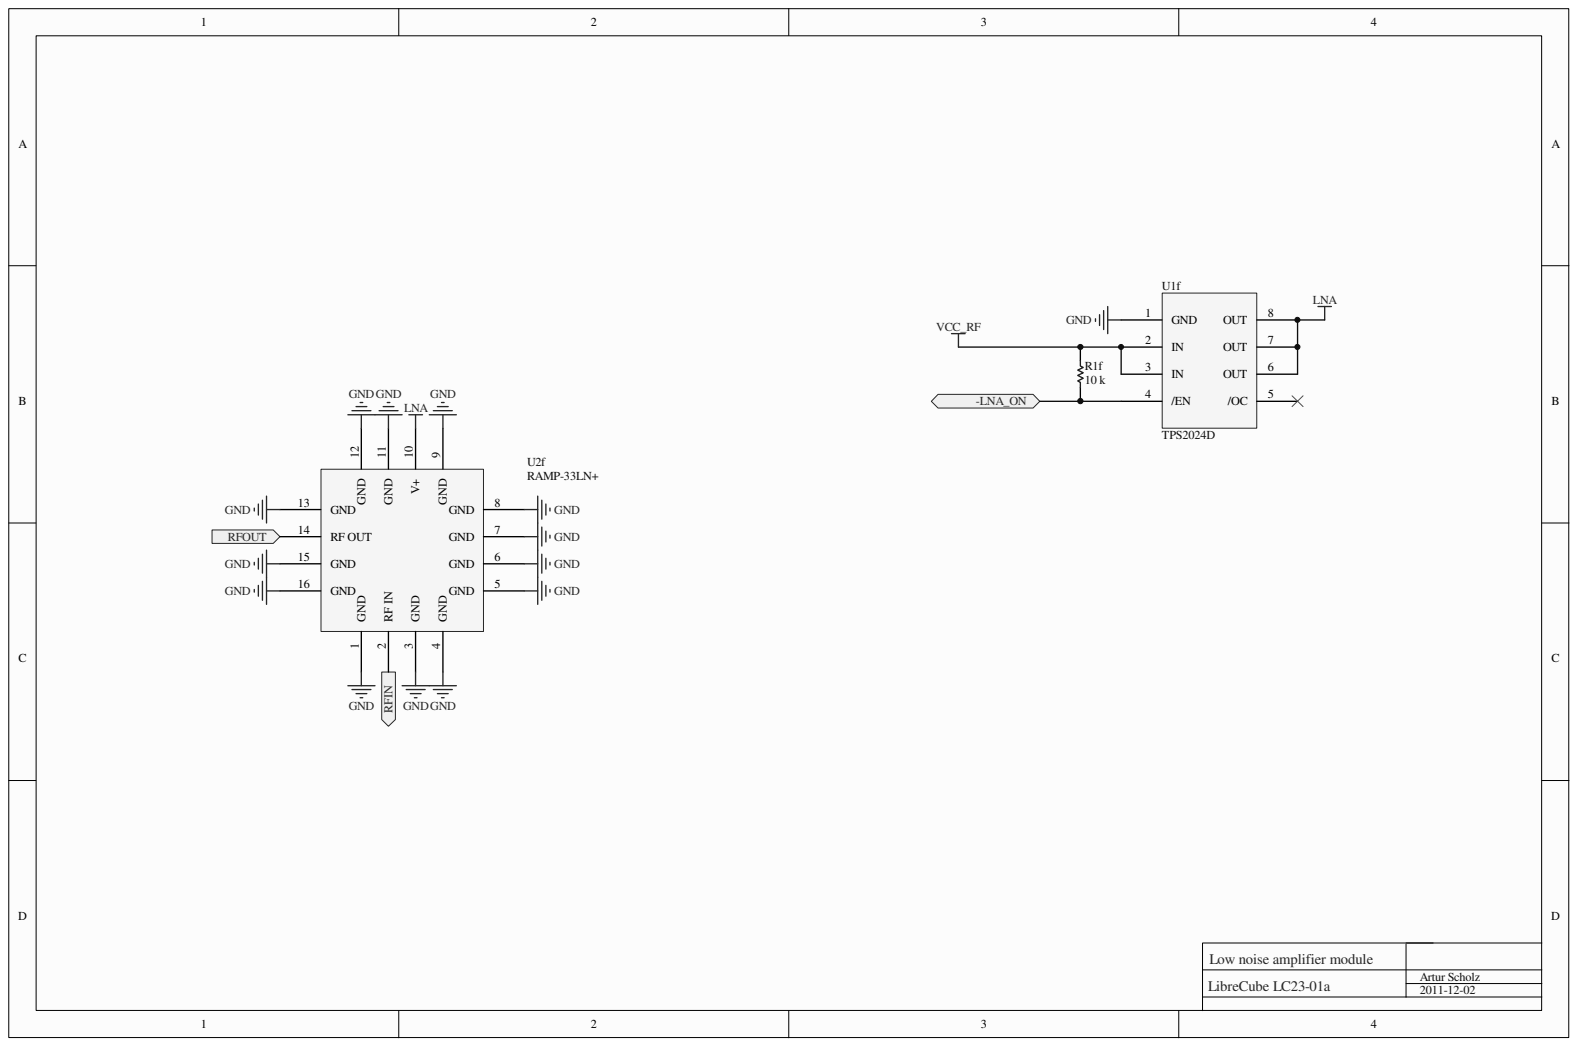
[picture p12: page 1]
Artur Scholz; LibreCube LC23-01a; RFOUT; RFIN; LNA; -LNA_ON; GND; GND 8; GND 13; RF OUT 14; GND 15; GND 16; U2f RAMP-33LN+; GNDGND; GND 1; OUT; TPS2024D; VCC_RF

Low noise amplifier module

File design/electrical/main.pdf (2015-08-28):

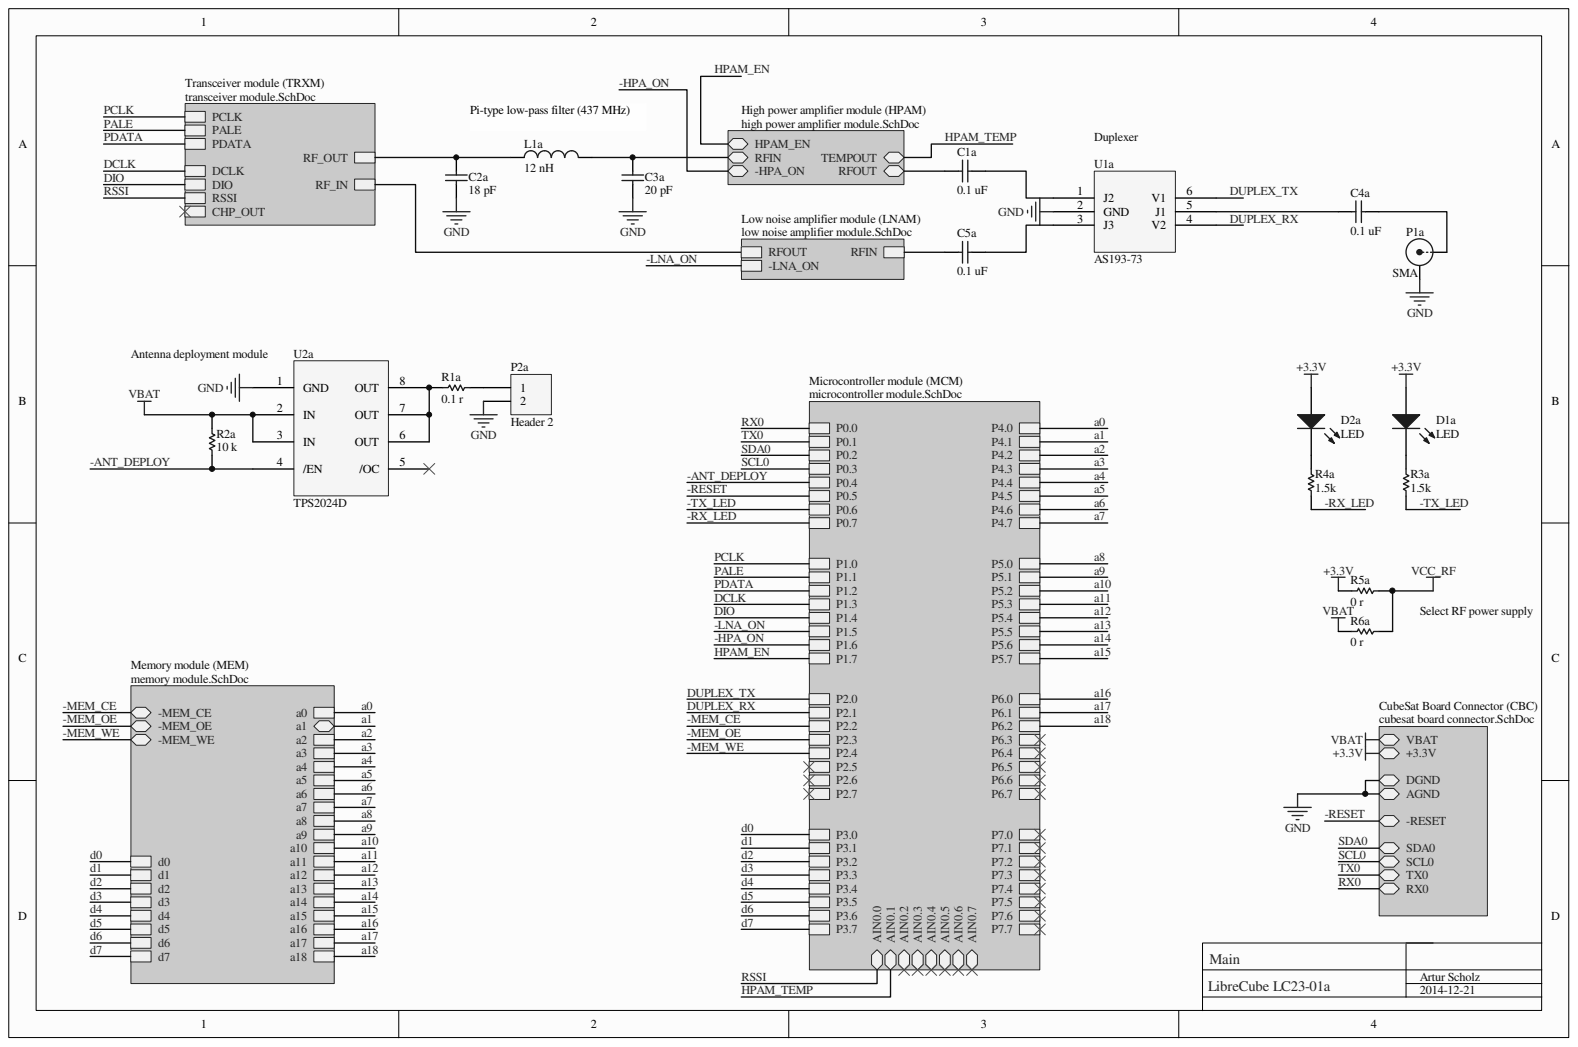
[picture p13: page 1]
Artur Scholz; Main; LibreCube LC23-01a; SDA0 SCL0; -RESET; AGND; DGND; DCLK DIO RSSI CHP_OUT; RF_OUT; RFOUT; TEMPOUT; SMA; GND; PCLK PALE PDATA; DCLK DIO RSSI; Header 2; VBAT; OUT; TPS2024D; -ANT_DEPLOY; DUPLEX_TX; DUPLEX_RX; HPAM_EN; -ANT_DEPLOY -RESET; -MEM_WE; -MEM_CE -MEM_OE; -MEM_CE; -MEM_OE; AIN0.0; AIN0.1; AIN0.2; AIN0.3; AIN0.4; AIN0.5; AIN0.6; AIN0.7; HPAM_TEMP; Duplexer; PCLK PALE PDATA DCLK DIO; RSSI HPAM_TEMP; D1a LED; D2a LED; -RX_LED; -TX_LED; -TX_LED -RX_LED; -HPA_ON; RFIN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

Transceiver module (TRXM)
transceiver module.SchDoc
PCLK
PALE
PDATA

Pi-type low-pass filter (437 MHz)

High power amplifier module (HPAM)
high power amplifier module.SchDoc
HPAM_EN
RFIN
-HPA_ON

Low noise amplifier module (LNAM)
low noise amplifier module.SchDoc
-LNA_ON

Antenna deployment module

Microcontroller module (MCM)
microcontroller module.SchDoc

Select RF power supply

Memory module (MEM)
memory module.SchDoc

CubeSat Board Connector (CBC)
cubesat board connector.SchDoc
VBAT

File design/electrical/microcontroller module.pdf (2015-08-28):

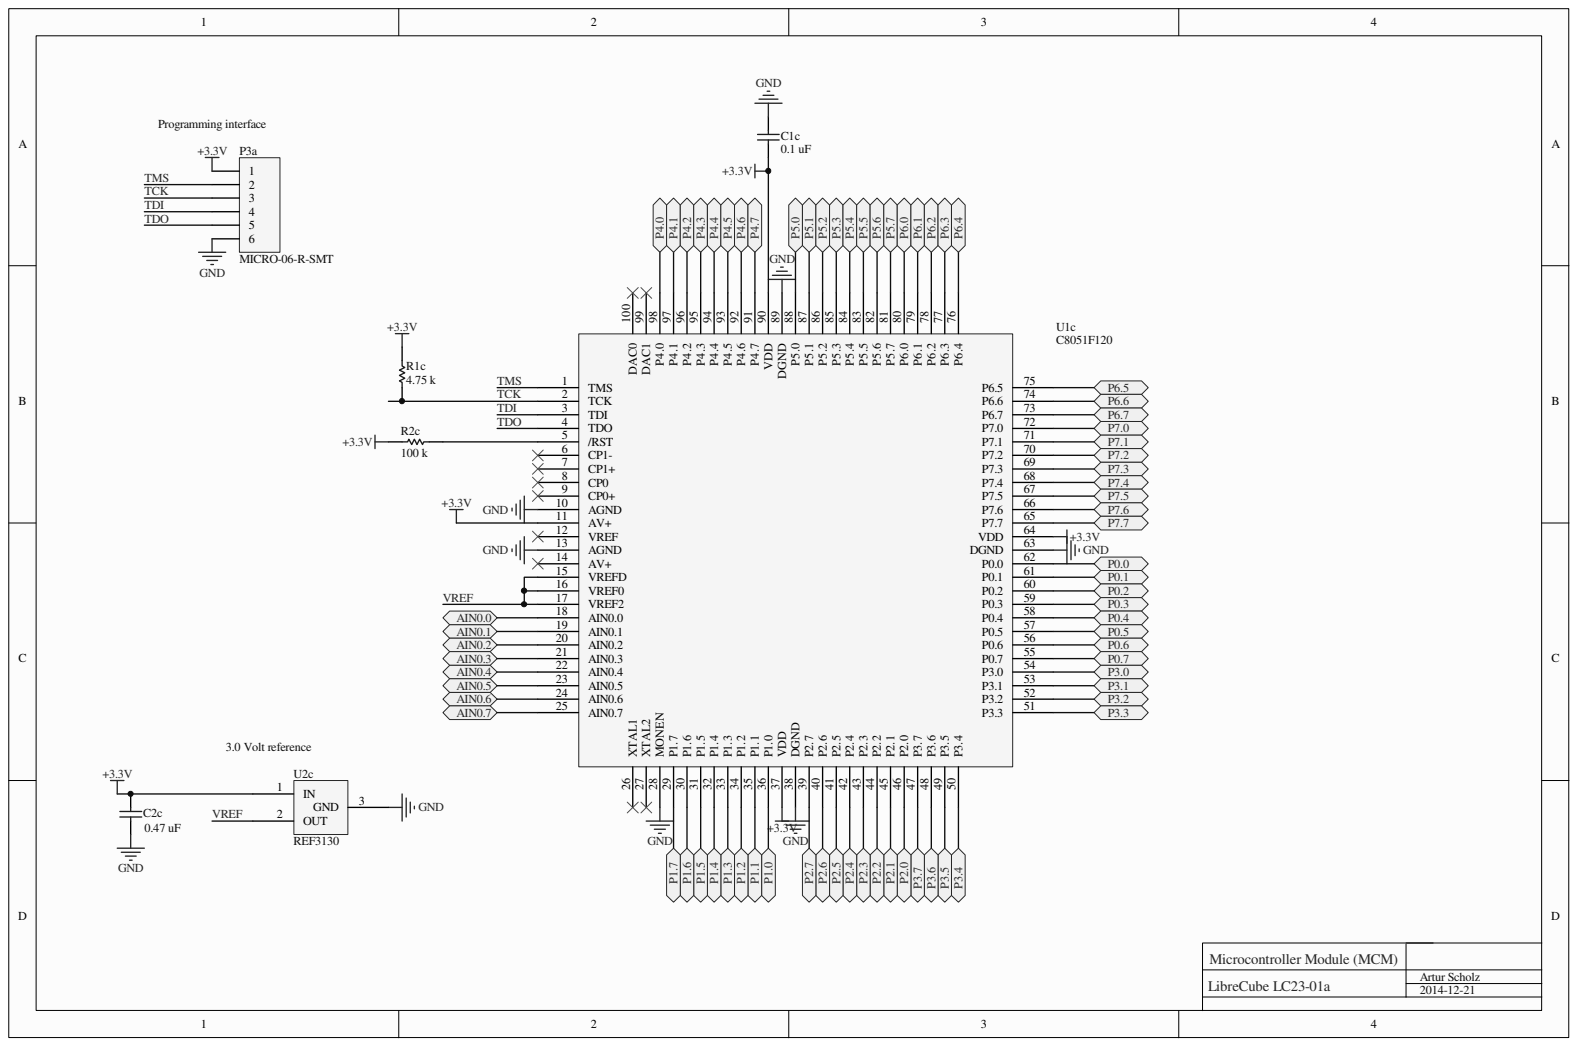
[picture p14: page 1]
Artur Scholz; LibreCube LC23-01a; TMS 1 TCK 2 TDI 3 TDO 4 /RST 5 CP1- 6 CP1+ 7 CP0 8 CP0+ 9 AGND 10 AV+ 11 VREF 12 AGND 13 AV+ 14 VREFD 15 VREF0 16 VREF2 17 AIN0.0 18 AIN0.1 19 AIN0.2 20 AIN0.3 21 AIN0.4 22 AIN0.5 23 AIN0.6 24 AIN0.7 25; XTAL1; XTAL2; MONEN; VDD; DGND; 62 DGND; 63 VDD; DAC1; DAC0; GND; OUT 2; REF3130; 3.0 Volt reference; VREF; AIN0.0 AIN0.1 AIN0.2 AIN0.3 AIN0.4 AIN0.5 AIN0.6 AIN0.7; Programming interface; TMS TCK TDI TDO; MICRO-06-R-SMT

Microcontroller Module (MCM)

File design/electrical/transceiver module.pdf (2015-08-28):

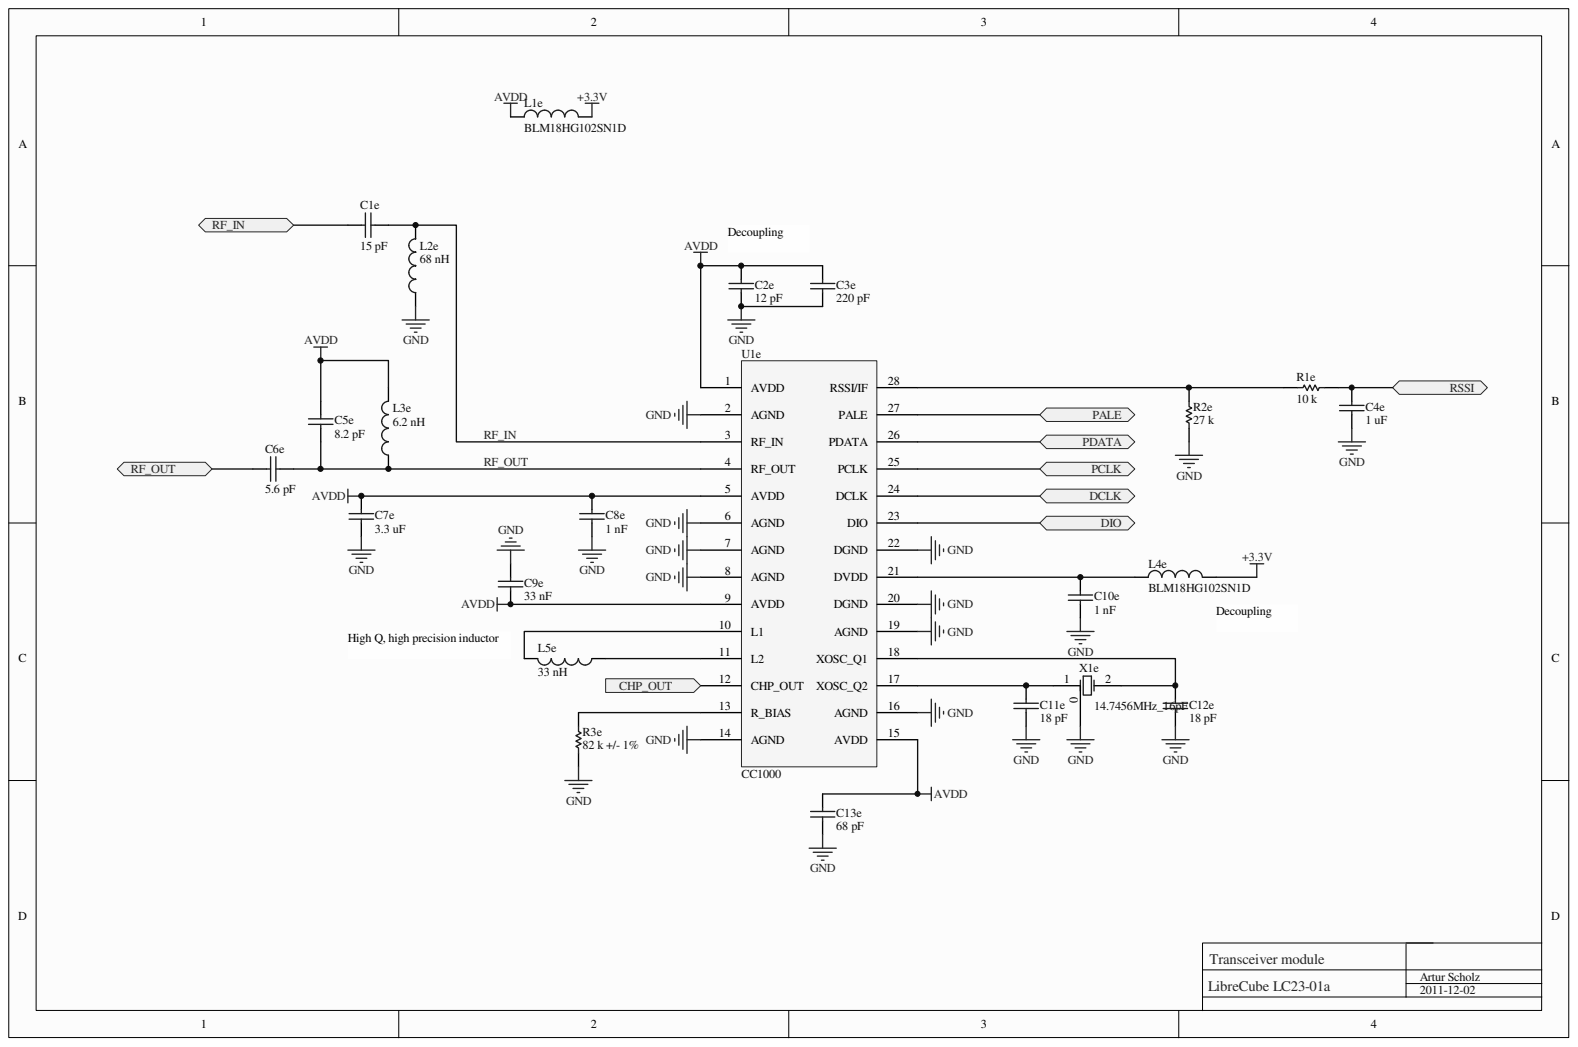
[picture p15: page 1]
Artur Scholz; Transceiver module; LibreCube LC23-01a; AVDD 1; AGND 2; RF_OUT 4; AVDD 5; AGND 6; AGND 7; AGND 8; AVDD 9; CHP_OUT 12; R_BIAS 13; AGND 14; AVDD; AGND; XOSC_Q2; XOSC_Q1; DGND; DVDD; DIO; DCLK; PCLK; PDATA; PALE; RSSI/IF; 14.7456MHz_16pF; RSSI; GND; CHP_OUT; RF_OUT; BLM18HG102SN1D; GND C9e; Decoupling; AVDDL1e

High Q, high precision inductor

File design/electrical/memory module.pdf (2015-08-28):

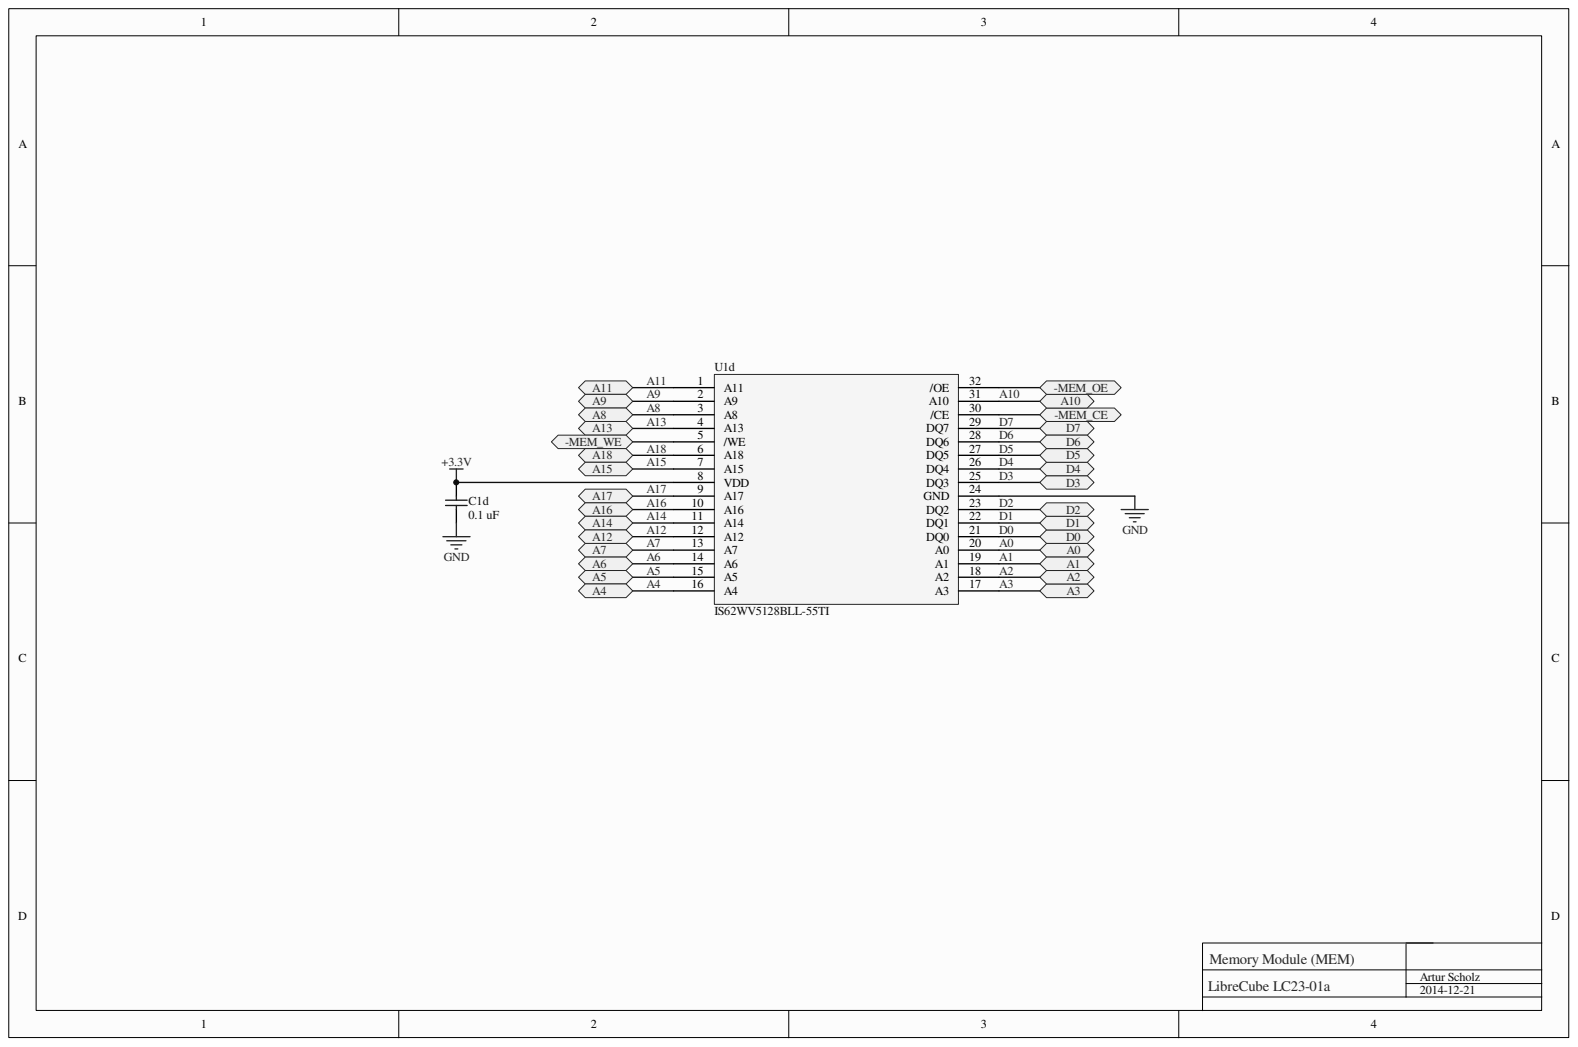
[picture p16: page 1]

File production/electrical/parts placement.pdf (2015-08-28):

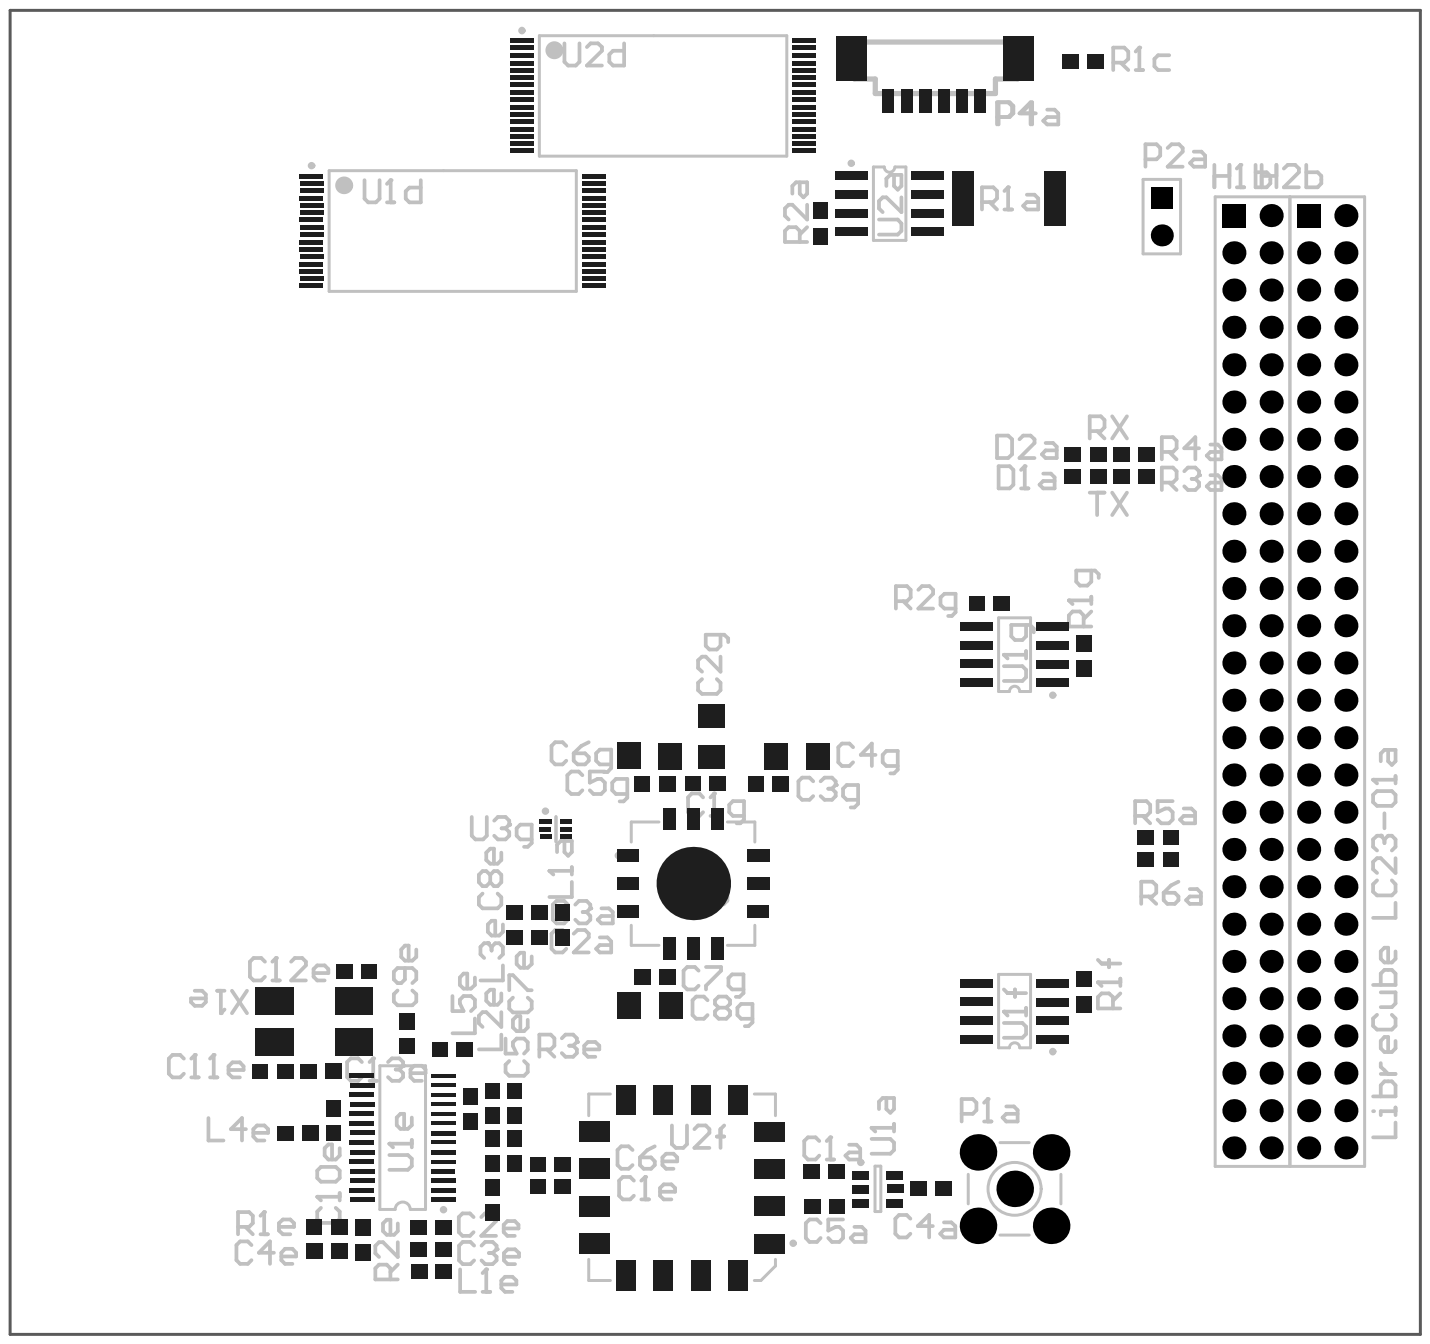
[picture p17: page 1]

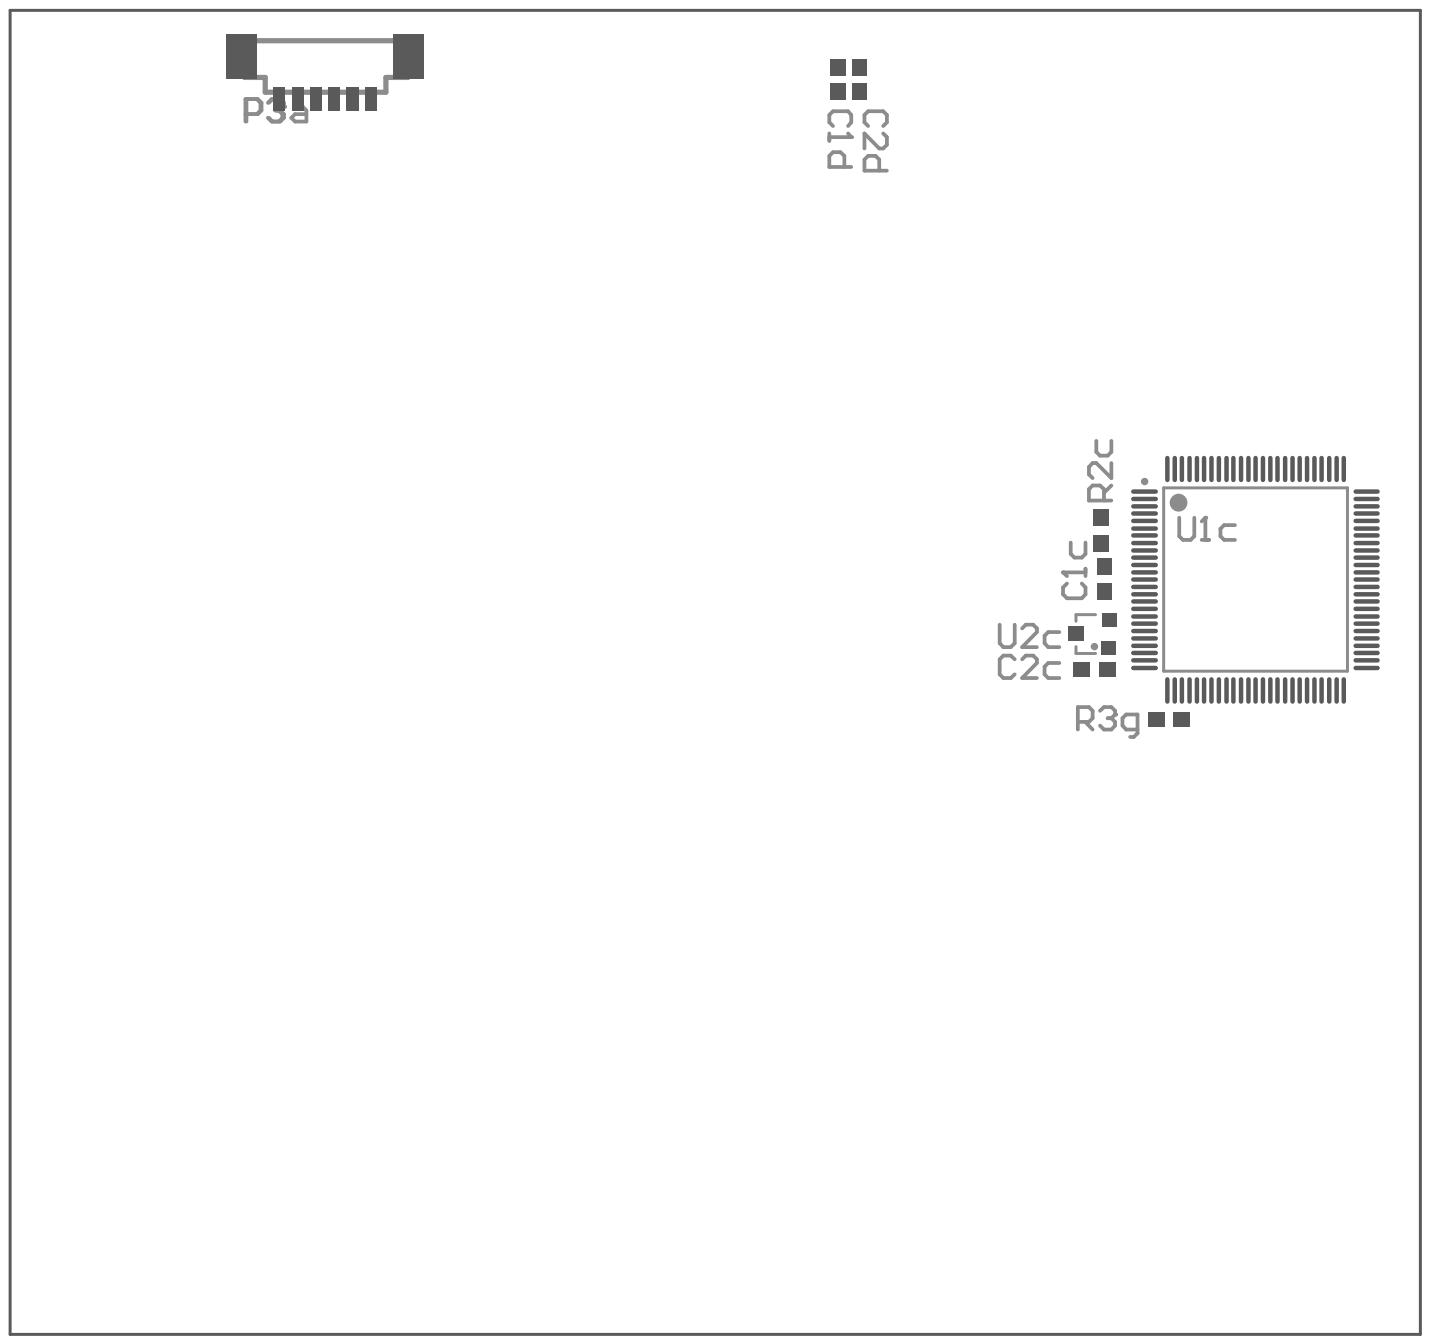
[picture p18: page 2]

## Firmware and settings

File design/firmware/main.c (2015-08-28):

/* ---------------------------------------
 * LibreCube LC-2301a Communication System
 * ---------------------------------------
 * Last update: 2014-11-18
 */

/*	To do:
 *		- add automatic ping mode? (i.e. send beacon when i2c idle for long duration)
 *		- implement watchdog timer
 *		- add i2c timeouts
 */

/* Includes */
#include "definitions.h"
#include "modules/c8051f120.h"
#include "functions/common.h"
#include "functions/telecommand.h"
#include "functions/telemetry.h"

/* Global variables */
Register_t reg;
uint8_t *regPtr = (uint8_t*) (&reg);
uint8_t targetReg = 0;
uint8_t targetRegFlag = 0;
uint8_t value = 0;
uint8_t valueFlag = 0;
uint32_t timerHk = 0;
uint32_t timer2Val = 0;
uint16_t tcOctetsIn = 0;
uint16_t tcOctetsOut = 0;
uint16_t tmOctetsIn = 0;
uint16_t tmOctetsOut = 0;

void main(void)
{
    InitRegister(); /* Load default register values */
    InitModules(); /* Configure and initialize hardware */
    
    /* Do the housekeeping measurements at boot */
    TriggerMeasurements();
    
    for (;;)
    {
        /* Execute a received command from I2C master */
        if (targetRegFlag && valueFlag)
        {
            RegWrite(targetReg, value);
            targetRegFlag = valueFlag = 0; /* Reset the flags afterwards */
        }

        /* Refresh housekeeping data, if timer expired */
        if ((reg.hkperiod != 0) && (timerHk >= reg.hkperiod))
        {
            timerHk = 0; /* Reset timer count */
            TriggerMeasurements();
        }          
        
        /* Are there TC bytes in the FIFO? */
		if (tcOctetsOut != tcOctetsIn) 
		{			
		    PopTcFifo(); /* Pop one byte from FIFO and route to UART0 */
		}

		/* Are there TM bytes in the FIFO? */
		if (tmOctetsOut != tmOctetsIn) 
		{
		    if (reg.flag.tx_enabled == SET) /* Is TX enabled? */
            {
		        if (reg.flag.tx_on == CLEAR) /* If TX is not on yet, switch it on */ 
		        {
		            StartTransmission();     
		        }
		        
                PopTmFifo(); /* Pop one byte from FIFO and route to transmitter */
            }
		    else
		    {
		        tmOctetsOut++; /* Otherwise skip this byte */
		    }
		}
		else /* Switch off TX after all FIFO data has been transmitted */
		{
			if (reg.flag.tx_on == SET) /* Check if TX is still on */
			{
				EndTransmission();
			}
		}
    }
}

void Timer0Isr(void) __interrupt 1 /* called every 0.00005 sec for sampling rx input */
{
    DetectCltuStartSequence();  
}

void SystemResetIsr(void) __interrupt 2 /* triggers when -RESET line is low */
{   
    MicrocontrollerReset();
}

void Timer2Isr(void) __interrupt 5 /* called every 0.01 sec, for hk period */
{
    timer2Val++;    
    if (timer2Val >= 10)
    {
        timer2Val = 0;
        timerHk++;    // increases every 0.1 sec
    }
    TF2 = 0;    /* clear interrupt flag (necessary) */
}

void I2cIsr(void) __interrupt 7 
{
    switch (SMB0STA)
    {
        case I2C_SROADACK:    /* (SR) own address + W received; ACK transmitted */
            targetRegFlag = 0;
            valueFlag = 0;
            break;
            
        case I2C_SRSTOP:    /* (SR) STOP or repeated START received while addressed as a slave */
            valueFlag = 0;
            AA = 1;
            break;
            
        case I2C_SRODBACK:    /* (SR) data byte received under own slave address; ACK returned */
            if (!targetRegFlag)    /* if this is the first byte */
            {
                targetRegFlag = 1;
                targetReg = SMB0DAT;
            }
            else    /* otherwise load second byte */
            {
                valueFlag = 1;
                value = SMB0DAT;
            }
            break;
            
        case I2C_STOADACK:    /* (ST) I2Cs own slave address + R received; ACK transmitted */
            SMB0DAT = regPtr[targetReg];
            break;
            
        case I2C_SRODBNACK:    /* (SR) data byte received under own slave address; NACK returned */
        case I2C_STDBNACK:    /* (ST) data byte transmitted; NACK received */
        case I2C_STDBLAST:    /* (ST) last data byte transmitted (AA=0); ACK received */
        case I2C_BUS_ERROR:
        default:    /* All other status codes meaningless in this application. */   
            STO = 1;    /* Reset communication. */
            break;
    }
    SI = 0;
}

void UartIsr(void) __interrupt 4
{   
    if (RI0) /* Push incoming data into TM FIFO */   
    {
		MemWrite(TM_FIFO, tmOctetsIn >> 8, tmOctetsIn & 0xFF, SBUF0);
		tmOctetsIn++;
		RI0 = 0;
    }
    
    if (TI0) 
    {
        TI0 = 0;
    }
}

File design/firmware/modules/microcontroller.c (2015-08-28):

/* ---------------------------------------
 * LibreCube LC-2301a Communication System
 * ---------------------------------------
 */

#include "microcontroller.h"

void Reset_Sources_Init()
{
    WDTCN = 0xDE;
    WDTCN = 0xAD;
    SFRPAGE = LEGACY_PAGE;
    RSTSRC = 0x06;
}

void Timer_Init()
{
    SFRPAGE = TIMER01_PAGE;
    TCON = 0x54;
    TMOD = 0x22;
    CKCON = 0x10;
    TL0 = TH0 = 0xE6;
    TH1 = 0xEC;
    SFRPAGE = TMR2_PAGE;
    TMR2CN = 0x04;
    TMR2CF = 0x08;
    RCAP2H = 0x0F;
    TMR2H = 0x0F;
}

void UART_Init()
{
    SFRPAGE = UART0_PAGE;
    SCON0 = 0x50;
}

void SMBus_Init()
{
    SFRPAGE = SMB0_PAGE;
    SMB0CN = 0x40;
    SMB0CR = 0xFA;
}

void Voltage_Reference_Init()
{
    SFRPAGE = ADC0_PAGE;
    REF0CN = 0x06;
}

void Port_IO_Init()
{
    // P0.0  -  TX0 (UART0), Push-Pull,  Digital
    // P0.1  -  RX0 (UART0), Open-Drain, Digital
    // P0.2  -  SDA (SMBus), Open-Drain, Digital
    // P0.3  -  SCL (SMBus), Open-Drain, Digital
    // P0.4  -  INT0 (Tmr0), Open-Drain, Digital
    // P0.5  -  INT1 (Tmr1), Open-Drain, Digital
    // P0.6  -  Unassigned,  Open-Drain, Digital
    // P0.7  -  Unassigned,  Open-Drain, Digital
    
    // P1.0  -  Unassigned,  Push-Pull,  Digital
    // P1.1  -  Unassigned,  Push-Pull,  Digital
    // P1.2  -  Unassigned,  Push-Pull,  Digital
    // P1.3  -  Unassigned,  Open-Drain, Digital
    // P1.4  -  Unassigned,  Push-Pull,  Digital
    // P1.5  -  Unassigned,  Open-Drain, Digital
    // P1.6  -  Unassigned,  Open-Drain, Digital
    // P1.7  -  Unassigned,  Push-Pull,  Digital
    
    // P2.0  -  Unassigned,  Push-Pull,  Digital
    // P2.1  -  Unassigned,  Push-Pull,  Digital
    // P2.2  -  Unassigned,  Push-Pull,  Digital
    // P2.3  -  Unassigned,  Push-Pull,  Digital
    // P2.4  -  Unassigned,  Push-Pull,  Digital
    // P2.5  -  Unassigned,  Push-Pull,  Digital
    // P2.6  -  Unassigned,  Push-Pull,  Digital
    // P2.7  -  Unassigned,  Push-Pull,  Digital
    
    // P3.0  -  Unassigned,  Open-Drain, Digital
    // P3.1  -  Unassigned,  Open-Drain, Digital
    // P3.2  -  Unassigned,  Open-Drain, Digital
    // P3.3  -  Unassigned,  Open-Drain, Digital
    // P3.4  -  Unassigned,  Open-Drain, Digital
    // P3.5  -  Unassigned,  Open-Drain, Digital
    // P3.6  -  Unassigned,  Open-Drain, Digital
    // P3.7  -  Unassigned,  Open-Drain, Digital
    
    SFRPAGE = CONFIG_PAGE;
    P0MDOUT = 0x01;
    P1MDOUT = 0x97;
    P2MDOUT = 0xFF;
    P4MDOUT = 0xFF;
    P5MDOUT = 0xFF;
    P6MDOUT = 0x07;
    XBR0 = 0x05;
    XBR1 = 0x14;
    XBR2 = 0x40;
    
    P0 = 0xFF;
}

void Oscillator_Init()
{
    SFRPAGE = CONFIG_PAGE;
    OSCICN = 0x81;
}

void Interrupts_Init()
{
    IE = 0xB6;
    IP = 0x26;
    EIE1 = 0x02;
    EIP1 = 0x02;
}

void MicrocontrollerInit(void)
{
    Reset_Sources_Init();			// disable WDT
    Timer_Init();	
    UART_Init();				// 9600 bps
    SMBus_Init();				// 100 kHz
    Voltage_Reference_Init();
    Port_IO_Init();
    Oscillator_Init();				// 6.126 MHz
    Interrupts_Init();				
    AdcInit();
}

void MicrocontrollerReset(void)
{
    RSTSRC = RSTSRC | 0x10;
}

void AdcInit(void)
{
    uint8_t SAVEPAGE = SFRPAGE;
    SFRPAGE = ADC0_PAGE;
    
    ADC0CN = 0xC0;
    
    SFRPAGE = SAVEPAGE;
}

void AdcState(const uint8_t state)
{
    if (state == ON)
        AD0EN = 1;
    else if (state == OFF)
        AD0EN = 0;
}

uint16_t AdcMeasure(const uint8_t channel)
{
    uint16_t buffer;
    uint8_t SAVEPAGE = SFRPAGE;
    SFRPAGE = ADC0_PAGE;
    
    AMX0SL = channel; 		// 0 = AIN0.0, etc., 8 = TEMP			
    
    AD0INT = 0; 			// clear ADC interrupt flag 
    AD0BUSY = 1; 			// trigger conversion 
    while (!AD0INT)
        ; 		// wait for conversion to complete 
        
    buffer = (ADC0H & 0x0F);    // 12 bit ADC
    buffer = (buffer << 8) + ADC0L;
    
    SFRPAGE = SAVEPAGE;
    return buffer;    // return result as 16-bit value
}

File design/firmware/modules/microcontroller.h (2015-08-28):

/* ---------------------------------------
 * LibreCube LC-2301a Communication System
 * ---------------------------------------
 */

#ifndef	MICROCONTROLLER_H
#define MICROCONTROLLER_H

/* Includes */
#include "c8051f120.h"
#include "../definitions.h"

/* ADC specific */
#define ADC_TEMP	8
#define ADC_AIN0	0
#define ADC_AIN1	1

/* Pin allocations */
#define _ANT_DEPLOY		        P0_4
#define _TX_LED                 P0_6
#define _RX_LED                 P0_7
#define TRX_PCLK                P1_0
#define TRX_PALE                P1_1
#define TRX_PDATA               P1_2
#define TRX_DCLK                P1_3
#define TRX_DIO                 P1_4
#define _LNA_ON                 P1_5
#define _HPA_ON                 P1_6
#define HPAM_EN                 P1_7
#define DUPLEX_TX               P2_0
#define DUPLEX_RX               P2_1
#define _MEM_CE                 P2_2
#define _MEM_OE                 P2_3
#define _MEM_WE                 P2_4
#define DATA                    P3
#define ADDRESS_L               P4
#define ADDRESS_M               P5
#define ADDRESS_H               P6

/* Function declarations */
void MicrocontrollerInit(void);
void MicrocontrollerReset(void);
void AdcInit(void);
void AdcState(const uint8_t state);
uint16_t AdcMeasure(const uint8_t channel);

#endif

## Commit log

2017-01-25 Started KiCad redesign
    [communication_system.kicad_pcb, communication_system.sch, cubesat_board_connector.sch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]
2017-01-29 Finished schematics
    [communication_system.sch, cubesat_board_connector.sch, high_power_amplifier_module.sch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]
